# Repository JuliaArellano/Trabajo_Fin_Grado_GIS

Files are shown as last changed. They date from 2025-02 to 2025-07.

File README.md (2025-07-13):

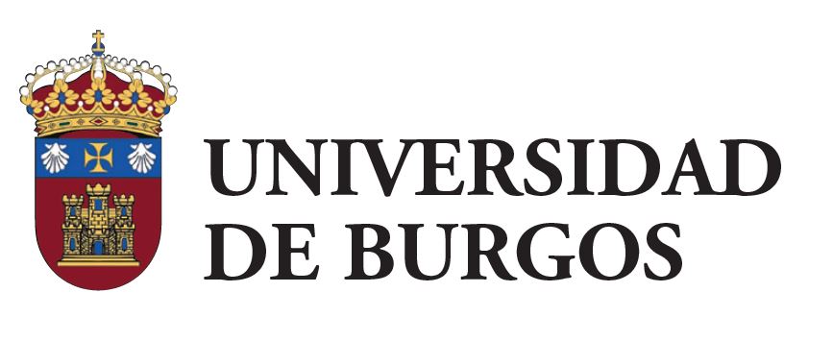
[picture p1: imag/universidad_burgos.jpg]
# Estudio de Viabilidad y Diseño Conceptual de un Stent Arterial Inteligente con regulación basada en sensores. 
**Autora:** Julia Arellano Atienza  
**Tutor:** Guirguis Zaki Guirguis Abdelmessih  
**Grado en Ingeniería de la Salud**  
**Universidad de Burgos** 

---

## Introducción

Las enfermedades cardiovasculares representan aproximadamente el 32 % de todas las muertes a nivel mundial, situándose como la principal causa de fallecimiento. Entre las patologías más comunes se encuentra la arterioesclerosis, caracterizada por el estrechamiento de las arterias debido a la acumulación de placas de ateroma, lo que limita el flujo sanguíneo y puede derivar en eventos isquémicos graves, como infarto de miocardio o accidente cerebrovascular.

Para tratar estas obstrucciones, la implantación de stents es una estrategia habitual que permite mantener abierto el vaso sanguíneo afectado y restaurar el flujo sanguíneo. Desde su introducción, los stents han evolucionado incluyendo variantes farmacoactivas y recubiertas con polímeros para reducir complicaciones. Sin embargo, aún presentan limitaciones importantes: entre un 20 % y un 30 % de los pacientes desarrollan reestenosis (re-estrechamiento del vaso) y existe riesgo de trombosis del stent, complicación potencialmente mortal. Además, los stents actuales carecen de mecanismos de monitorización en tiempo real, dificultando la detección precoz de estas complicaciones.

Frente a esta necesidad, surgen los stents inteligentes con sensores integrados, capaces de monitorizar parámetros fisiológicos como presión, flujo o rigidez arterial, proporcionando datos continuos para la evaluación clínica y la personalización del tratamiento.

---
## Objetivo General

El presente proyecto tiene como objetivo el diseño conceptual de un stent inteligente con sensores integrados, orientado a mejorar la detección precoz de complicaciones como la reestenosis y la trombosis, así como a facilitar un seguimiento más efectivo y personalizado de los pacientes tras la intervención.

El proyecto incluye el diseño y evaluación del prototipo conceptual mediante análisis bibliográfico y modelado matemático, buscando su viabilidad funcional y su posible aplicación clínica futura.

---
## Resultados

A continuación se muestra el diseño 3D del stent inteligente desarrollado:

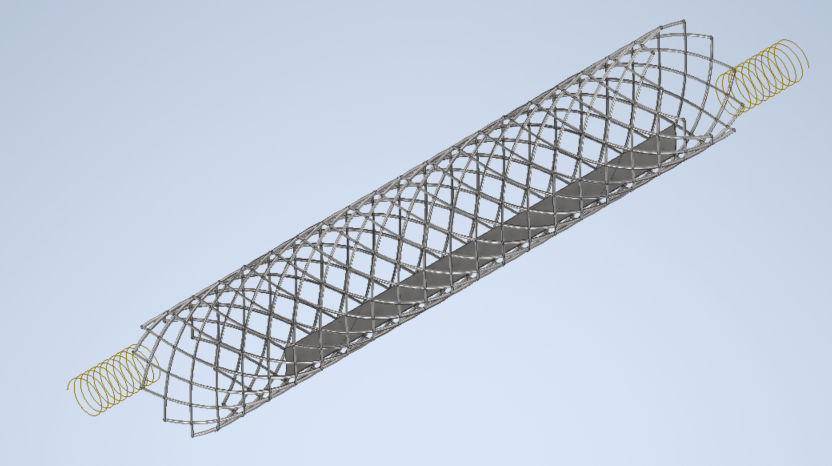
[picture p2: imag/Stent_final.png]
Modelo 3D del Stent Inteligente
  
*Figura 1. Vista del stent inteligente.*

También se ha implementado una aplicación interactiva que permite visualizar el stent, simular su comportamiento ante distintas condiciones y analizar los parámetros del sistema:

🔗 [Haz clic aquí para acceder a la aplicación](https://tfg-gis-stent-inteligente.streamlit.app/)

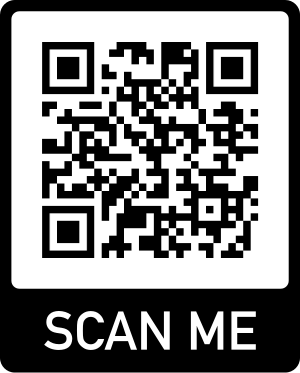
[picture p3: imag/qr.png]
Aplicación
  
*Figura 2. QR de la aplicación.*

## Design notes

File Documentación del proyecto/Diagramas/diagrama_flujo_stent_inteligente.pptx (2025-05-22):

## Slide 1

INICIO

Transmisión energía

LOCALIZACIÓN: PARCHE RECEPTOR

LOCALIZACIÓN: STENT INTELIGENTE

Bobinas reciben la señal electromagnética

Circuito LC se activa y mide la capacitancia (sensor)

Se transmiten los datos a través de las bobinas

¿Se reciben los datos por la bobina del parche?

Procesa y transforma los datos recibidos

Transmite los datos recibidos vía Bluetooth

No

LOCALIZACIÓN: PARCHE RECEPTOR

Sí

Microcontrolador

LOCALIZACIÓN: SISTEMA RECEPTOR

Recibe los datos y los muestra

FIN

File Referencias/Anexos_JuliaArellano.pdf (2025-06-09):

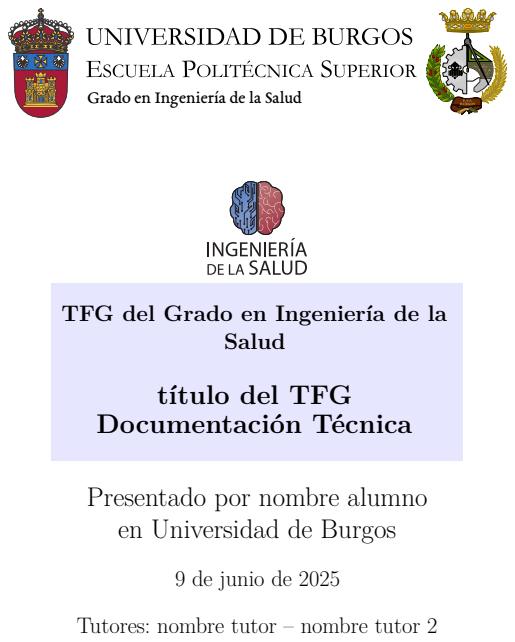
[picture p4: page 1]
Salud

Grado en Ingeniería de la Salud

TFG del Grado en Ingeniería de la

título del TFG
Documentación Técnica

Presentado por nombre alumno
en Universidad de Burgos

9 de junio de 2025

Tutores: nombre tutor – nombre tutor 2

# Índice general

Índice general | i
Índice de figuras | iii
Índice de tablas | v
Apéndice A Plan de Proyecto Software | 1
Apéndice B Documentación de usuario | 9
B.1. Requisitos software y hardware para ejecutar el proyecto. . . | 9

Apéndice C Manual del desarrollador / programador / in-
vestigador. | 11
C.4. Instrucciones para la modificación o mejora del proyecto. . . | 12

Apéndice D Descripción de adquisición y tratamiento de datos 13

Apéndice E Manual de especificación de diseño | 21

i

ii | Índice general
Apéndice F Especificación de Requisitos | 31
Apéndice G Estudio experimental | 33
Apéndice H Anexo de sostenibilización curricular | 63
Bibliografía | 67

# Índice de figuras

A.1. Planificación temporal . Fuente Propia | | 7
D.1. Estructura del Stent. Fuente Propia | | 17
D.2. (a) Posición del sensor en el stent y (b) Estructura del stent.
Fuente propia | | 18
D.3. Estructura de las bobinas. Fuente Propia | | 19
E.1. Plano del diseño inicial del stent . Fuente Propia | | 23
E.2. Plano del diseño stent inteligente . Fuente Propia | | 23
E.3. Plano del diseño del sensor capacitivo . Fuente Propia | | 24
E.4. Sección A del plano del sensor . Fuente Propia | | 24
E.5. Esquema eléctrico de conexión entre el stent y el sistema externo.
Fuente propia | 27
E.6. Diagrama de flujo del sistema de comunicación entre el parche externo, el stent inteligente y el dispositivo receptor. Fuente propia. 28
E.7. Diagrama de componentes de la aplicación | 29
E.8. Diagrama de despliegue de la aplicación web en Streamlit Cloud. 29 E.9. Diagrama de secuencia de interacción entre el usuario y el sistema. 30
G.1. Diseño del stent inteligente final. Fuente Propia | 53
G.2. Inicio de la simulación de la expansión del Nitinol (a) y Fin de
la expansión del Nitinol. Fuente Propia | 53
G.3. Simulación de la expansión térmica del diámetro del stent de
Nitinol Fuente Propia | 54
G.4. Simulación de la expansión térmica de la longitud del stent de
Nitinol. Fuente propia | | 55
G.5. Perfil de velocidad en reposo. Fuente Propia | | 56
G.6. Perfil de velocidad en actividad. Fuente propia | | 56

iii

iv | Índice de figuras
G.7. Impacto de la estenosis en el stent. Fuente Propia | | 57
G.8. Analisis de variación de la frecuencia. Fuente Propia | | 59
G.9. Variación de las tensiones en reposo. Fuente Propia | | 61
G.10.Variación de las tensiones en reposo. Fuente Propia | | 62

# Índice de tablas

A.1. Costes de dispositivos hardware | | 2
A.2. Costes de software utilizados en el proyecto | | 3
A.3. Costes de personal estimados para el desarrollo del proyecto. . . | 3
A.4. Resumen de costes totales del proyecto | | 3
D.1. Parámetros técnicos del stent | | 13
D.2. Características técnicas del sensor capacitivo | | 14
D.3. Estructura en capas del sensor capacitivo | | 14
D.4. Parámetros técnicos del sistema de comunicación | | 15
F.1. CU-1 Nombre del caso de uso | | 32
G.1. Configuración de la expansión del Nitinol | | 46
G.2. Parámetros utilizados para el análisis del flujo sanguíneo en el
interior del stent | 48
G.3. Parámetros geométricos utilizados para el cálculo de la inductan-
cia de la bobina integrada en el stent | 49
G.4. Parámetros utilizados para el cálculo de la capacitancia total del
sensor capacitivo | 49
G.5. Parámetros utilizados en el cálculo de la frecuencia de resonancia
del circuito LC | 50
G.6. Parámetros utilizados en el cálculo de la resistencia de la bobina
y el factor de calidad Q | 50
G.7. Parámetros de la bobina externa utilizada para la transmisión
de energía y señal | | 51
G.8. Parámetros utilizados para calcular la distancia máxima | | 52

v

## Apéndice A

# Plan de Proyecto Software

## A.1. Introducción

Para garantizar el desarrollo adecuado del proyecto, es fundamental realizar una planificación estructurada que contemple tanto los aspectos temporales como los recursos económicos necesarios. Además, resulta imprescindible analizar la viabilidad legal para asegurar que el diseño y aplicación del sistema propuesto cumpla con la normativa vigente. A continuación, se detalla la planificación temporal, económica y legal del proyecto.

## A.2. Planificación temporal

Para el desarrollo del presente trabajo se ha seguido una metodología combinada basada en el modelo en cascada y ciertos principios de Scrum, con el fin de estructurar el proceso de forma clara pero manteniendo flexibilidad ante posibles cambios o mejoras.

El proyecto se ha dividido en hitos principales (milestones), cada uno de los cuales agrupa un conjunto de tareas específicas (issues) que responden a un objetivo común dentro del desarrollo del stent inteligente. Estos hitos incluyen desde la investigación inicial, pasando por el diseño básico y la integración de sensores, hasta el análisis de viabilidad, el desarrollo de la aplicación de visualización y la documentación final.

El enfoque en cascada permite avanzar de manera secuencial a través de las distintas fases del proyecto.No obstante, se han incorporado también prácticas propias de metodologías ágiles como Scrum, especialmente a través de reuniones periódicas de seguimiento semanal, que han facilitado el control

| 1

2 | Apéndice A. Plan de Proyecto Software

de avances, la detección temprana de dificultades y la incorporación de mejoras sobre la marcha.

La planificación del proyecto se representa en el diagrama de Gantt (figura A.1), donde se distingue en azul la planificación inicial y en verde la planificación finalmente llevada a cabo. Esta estructura ha sido clave para cumplir los plazos establecidos y mantener un flujo de trabajo constante y ordenado.

### A.2.1. Planificación económica

A continuación, se presenta la planificación económica del proyecto, en la que se estiman los recursos necesarios y los costes asociados al desarrollo del Trabajo Fin de Grado.

Costes de hardware

En el desarrollo de este proyecto únicamente se ha utilizado un dispositivo físico (un ordenador portátil). Para estimar su coste dentro del marco del Trabajo Fin de Grado, se ha calculado la amortización considerando una vida útil media del dispositivo de 4 años y en función de los 6 meses de duración del proyecto. En la Tabla A.1 se recoge el desglose de este coste

Dispositivo | Coste total | Amortización (6 meses)
Ordenador portátil V15 G2 ITL | 695,13 € [1] | 86,98 €

Tabla A.1: Costes de dispositivos hardware.

Costes de sotfware

En cuanto al software, se ha utilizado la versión gratuita de Anaconda (Python) y Streamlit, ambas de libre acceso, junto con Autodesk Inventor, para el diseño del stent, que dispone de una licencia de pago cuyo coste mensual se ha tenido en cuenta para calcular el coste total proporcional al uso durante los 6 meses del proyecto.

La Tabla A.2 resume los costes asociados a cada una de las herramientas.

Costes de personal

Para calcular los costes de personal correspondientes al desarrollo de este diseño de prototipo, se ha tomado como referencia el salario medio de un ingeniero biomédico contratado bajo un contrato indefinido en régimen

A.2. Planificación temporal | 3
Software | Tipo de licencia | Amortización (6 meses)
Autodesk Inventor | Licencia de pago (472 €/mes)[2] | 2.832 €
Anaconda (Python) | Gratuita | 0 €
Streamlit | Gratuita | 0 €

Tabla A.2: Costes de software utilizados en el proyecto.

general y a tiempo parcial de 5 horas diarias, considerando una duración del proyecto de 6 meses.

La Tabla A.3 detalla el desglose de los costes.

Concepto | Coste
Salario bruto mensual (5 horas diarias) | 1.743,75 € [3]
Coste seguridad social empresa (32,07 %) | 652,43 €[4]
Coste total mensual | 2.396,18 €
Coste total para 6 meses | 14.377,06 €

Tabla A.3: Costes de personal estimados para el desarrollo del proyecto.

Coste total

El precio de los materiales no se ha tenido en cuenta en este trabajo, ya que el diseño del prototipo se ha realizado únicamente de forma digital, dibujado con software especializado, sin llevar a cabo la fabricación o creación del dispositivo físico. Por tanto, los costes reflejados en la tabla A.4, corresponden exclusivamente al desarrollo del diseño digital y al uso del software necesario.

Concepto | Coste
Coste hardware Coste software Coste de personal | 86,98 € 2.832,00 € 14.377,08 €
Coste total estimado | 17.296,06

Tabla A.4: Resumen de costes totales del proyecto.

4 | Apéndice A. Plan de Proyecto Software
A.3. | Viabilidad legal

El desarrollo de un stent inteligente implantable requiere cumplir con una serie de normativas y regulaciones legales que garanticen su seguridad, eficacia, trazabilidad, protección industrial y tratamiento ético de los datos. Esta sección aborda la viabilidad legal considerando una futura fabricación, ensayo clínico y comercialización del dispositivo.

### A.3.1. Regulación Europea de Productos Sanitarios

El dispositivo se clasifica como un producto sanitario activo implantable de clase III, en base al Reglamento (UE) 2017/745 sobre productos sanitarios[5] que entra en vigor 25/05/2017 y en España se aplica desde 26/05/2021, denominado Medical Device Regulation (MDR). Esta normativa establece requisitos estrictos para productos de alto riesgo, incluyendo:

Evaluación clínica y elaboración del expediente técnico.

Aplicación de un sistema de gestión de calidad (ISO 13485)[6].

Gestión de riesgos según la norma ISO 14971[6].

Estudios de biocompatibilidad (ISO 10993)[6].

Obtención del marcado CE.

### A.3.2. Intervención de la AEMPS

La Agencia Española de Medicamentos y Productos Sanitarios (AEMPS) es el organismo competente en España para la supervisión, evaluación y autorización de productos sanitarios implantables [7]. Antes de su uso en humanos, el dispositivo requeriría:

Autorización para ensayos clínicos por parte de la AEMPS.

Aprobación por un Comité Ético de Investigación con medicamentos (CEIm).

Conformidad con los procedimientos definidos en el MDR y las guías técnicas nacionales.

A.3. Viabilidad legal | 5
A.3.3. | Normas Técnicas Aplicables

Durante el desarrollo del prototipo deben considerarse normas técnicas armonizadas con la legislación vigente, entre ellas:

ISO 13485: Gestión de calidad en productos sanitarios[6].

ISO 14971: Gestión del riesgo[6].

ISO 10993: Evaluación biológica de materiales[6].

ISO 25539: Requisitos específicos para stents vasculares[6].

ISO 14708-1: Dispositivos implantables activos electrónicos[6].

### A.3.4. Protección de la Propiedad Industrial

El diseño del stent inteligente podría ser registrado como patente conforme a la 24/2015, de Patentes [8]. Para ello, la invención debe cumplir los siguientes criterios:

Novedad.

Actividad inventiva.

Aplicación industrial.

La solicitud se tramitaría ante la Oficina Española de Patentes y Marcas (OEPM) y, posteriormente, podría extenderse internacionalmente mediante el Tratado de Cooperación en materia de Patentes (PCT) o a través de la Oficina Europea de Patentes (EPO).

### A.3.5. Protección de Datos Personales

En el caso de que el dispositivo se comercialice o se utilice en ensayos clínicos reales, será obligatorio cumplir con la normativa sobre protección de datos:

Reglamento General de Protección de Datos (RGPD) (UE) 2016/679 [9].

Ley Orgánica 3/2018, de Protección de Datos Personales y Garantía de los Derechos Digitales (LOPDGDD) [10].

6 | Apéndice A. Plan de Proyecto Software

Estas normativas regulan el tratamiento de datos personales de pacientes, estableciendo que:

El paciente debe otorgar un consentimiento informado específico y explícito.

Los datos deben ser anonimizados o pseudonimizados en los estudios.

Es necesaria la implementación de medidas técnicas y organizativas para garantizar la seguridad de la información.

### A.3.6. Equipos de Comunicación Inalámbrica

El sistema de comunicación inductiva incorporado al stent debe cumplir con la directiva 2014/53/UE (RED) relativa a equipos radioeléctricos [11]. Esta legislación exige:

Cumplimiento con normas de compatibilidad electromagnética (EMC).

Evaluación del uso eficiente del espectro radioeléctrico.

Garantía de que no se generan interferencias con otros dispositivos médicos.

### A.3.7. Conclusión Legal

A pesar de encontrarse en fase de diseño, el stent inteligente propuesto ha sido diseñado considerando los marcos normativos y legales relevantes. En una futura fase de comercialización, el cumplimiento de las directivas europeas, las normas ISO aplicables, la regulación española (AEMPS y OEPM) y la legislación de protección de datos asegurará la viabilidad legal del proyecto.

A.3. Viabilidad legal | 7

Figura A.1: Planificación temporal . Fuente Propia

## Apéndice B

# Documentación de usuario

B.1. Requisitos software y hardware para ejecutar el proyecto.

ver os requistos y decidir

B.2. | Instalación / Puesta en marcha
B.3. | Manuales y/o Demostraciones prácticas

9

## Apéndice C

# Manual del desarrollador /

programador / investigador.

## C.1. Estructura de directorios

Descripción de los directorios y ficheros entregados.

## C.2. Compilación, instalación y ejecución del proyecto

En caso de ser necesaria esta sección, porque la compilación o ejecución no sea directa.

## C.3. Pruebas del sistema

Esta sección puede ser opcional.

Puede tratarse de validación de la interfaz por parte de los usuarios, mediante escuestas o similar o validación del funcionamiento mediante pruebas unitarias.

| 11

12 | Apéndice C. Manual del desarrollador / programador / investigador.
C.4. | Instrucciones para la modificación o
mejora del proyecto.

Instrucciones y consejos para que el trabajo pueda ser mejorado en futuras ediciones.

## Apéndice D

# Descripción de adquisición y tratamiento de datos

## D.1. Descripción formal de los datos

Los datos correspondientes a este trabajo son los parámetros técnicos utilizados para el diseño conceptual del stent inteligente.

### D.1.1. Stent

Los valores definidos para la estructura del stent se muestran en la Tabla D.1.

Parámetro | Valor
Diámetro expandido Longitud total Espesor del hilo Tamaño del paso Número de hilos Material del stent | 3.55 mm 20 mm 0.1 mm 10 mm 6 hilos Nitinol

Tabla D.1: Parámetros técnicos del stent

13

14 | Apéndice D. Descripción de adquisición y tratamiento de datos
D.1.2. | Sensor capacitivo

Los valores relacionados con el sensor se muestran en la Tabla D.2.

Parámetro | Valor
Ubicación Dimensiones Espesor total del sensor Número de electrodos Dimensiones de los electro-dos Separación entre electrodos | Superficie interna del stent 1,05 mm × 15 mm 16 µm 48 pares 350 µm x 150µm 5 µm

Tabla D.2: Características técnicas del sensor capacitivo

Capas del sensor

Las capas que componen el sensor capacitivo se detallan en la Tabla D.3.

Capa | Material | Espesor
Capa superior Electrodo superior Capa intermedia Electrodo inferior Capa inferior Recubrimiento externo | Poliimida (PI) Nanopartículas de plata (AgNP) Poliimida (PI) (2 Capas super-puestas de 2.5 µm) Nanopartículas de plata (AgNP) Poliimida (PI) PDMS | 2.5 µm 1 µm 5 µm 1 µm 2.5 µm 4 µm

Tabla D.3: Estructura en capas del sensor capacitivo

D.1. Descripción formal de los datos | 15
D.1.3. | Sistema de comunicación

La información técnica del sistema de comunicación se basa en el uso de tecnología de acoplamiento inductivo (circuito LC), donde el condensador
(C) está constituido por el propio sensor capacitivo, mientras que las bobinas
(L) presentan las dimensiones recogidas en la Tabla D.4.
Parámetro | Valor
Ubicación Material conductor Diámetro exterior de la bo-bina Número de vueltas Espesor del hilo Longitud de la bobina | Extremos del stent Oro 1.2 mm 10 10 µm 2,5 cm

Tabla D.4: Parámetros técnicos del sistema de comunicación

### D.1.4. Conexiones

Las pistas conductoras se imprimen directamente sobre la superficie del stent utilizando oro recubiertas con una capa de poliamida. Estas pistas conectan eléctricamente las bobinas con los electrodos interdigitados del sensor. El espesor total de las conexiones es de 1 µm.

### D.1.5. Parche externo

El parche externo es fundamental en el sistema de comunicación inalámbrica y alimentación del stent inteligente. Su función principal sería transferir energía al stent y recibir la información generada por el sensor mediante acoplamiento inductivo, sin necesidad de cables ni contacto directo.

El diseño del parche incluiría los siguientes elementos clave:

Generador de señal u oscilador: Produce una corriente alterna a una frecuencia específica, que alimenta el circuito inductivo LC.

16 | Apéndice D. Descripción de adquisición y tratamiento de datos

Bobina transmisora (Lext): Genera un campo magnético alterno que induce corriente en la bobina del stent, proporcionando la energía necesaria para su funcionamiento.

Capacitor de sintonización (Cext): Forma un circuito resonante LC con la bobina transmisora, optimizando la transferencia de energía y señal entre el parche y el stent.

La bobina transmisora junto con el capacitor constituyen la parte pasiva del sistema, funcionando como circuito resonante o “antena” que permite tanto la transferencia de energía al stent como la recepción de la señal modulada que este transmite.

El circuito receptor activo del parche está compuesto por varios bloques electrónicos que procesan la señal recibida:

Rectificador: Convierte la señal alterna recibida en una señal continua adecuada para su procesamiento.

Conversor analógico-digital (ADC): Digitaliza la señal analógica modulada que proviene del stent.

Microcontrolador (MCU): Procesa y decodifica los datos digitalizados transmitidos desde el sensor capacitivo integrado en el stent.

Módulo Bluetooth Low Energy (BLE): Transmite inalámbricamente los datos procesados a dispositivos externos, como smartphones o sistemas de monitorización remota.

D.2. Descripción clínica de los datos.

Los parámetros definidos para el diseño del stent inteligente tienen como objetivo de tratar enfermedades cardiovasculares, más concretamente lesiones arteriales en arterias coronarias. A continuación, se presenta el significado clínico de cada uno de los parámetros seleccionados.

### D.2.1. Estructura del stent

Se ha seleccionado un diámetro expandido de 3.55 mm para el stent, ya que representa un valor promedio dentro del rango fisiológico de las arterias coronarias humanas, el cual varía entre 3 mm y 6 mm [12]. Esta

D.2. Descripción clínica de los datos. | 17

elección permite garantizar una adecuada apertura de la luz arterial tras la implantación, favoreciendo el restablecimiento del flujo sanguíneo.

La longitud del stent, de 20 mm, ha sido definida para cubrir eficazmente la zona afectada por la estenosis, sin invadir segmentos arteriales sanos. Esta dimensión se encuentra dentro del intervalo clínicamente recomendado para lesiones localizadas, que va de 0 a 20 mm.[12]

El stent está fabricado en Nitinol, una aleación con memoria de forma que permite recuperar su configuración original tras el despliegue en el vaso. Este material se emplea ampliamente en dispositivos médicos por su excelente biocompatibilidad, elasticidad y capacidad de adaptarse a los movimientos de la pared arterial [13].

En cuanto a sus características estructurales, el diseño incluye 6 hilos entrelazados con un espesor de 0.1 mm, que aseguran la estabilidad del dispositivo frente a las presiones internas del vaso sin comprometer su integridad estructural.

En la siguiente imagen, Figura D.1 se puede observar la estructura del stent diseñado

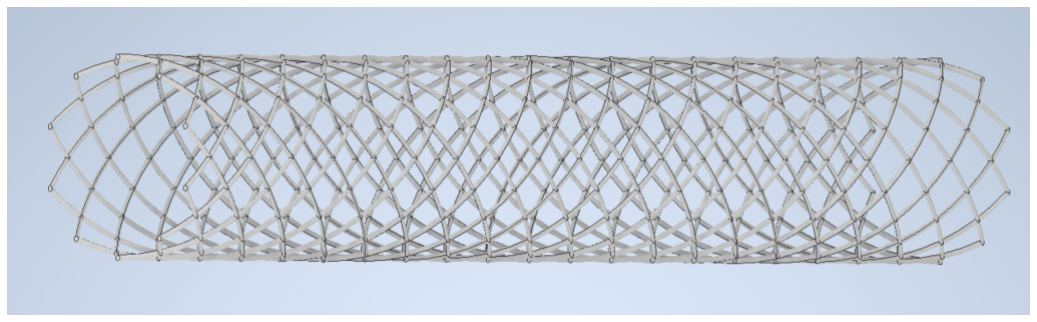
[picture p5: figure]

Figura D.1: Estructura del Stent. Fuente Propia

### D.2.2. Sensor capacitivo

El sensor capacitivo ha sido integrado en la superficie interna del stent, lo que permite obtener información fisiológica del entorno que lo rodea. Sus dimensiones (1.05 mm × 15 mm × 16 µm) han sido definidas para permitir su adaptación longitudinal a la pared interna del stent, sin alterar el flujo sanguíneo.

El número de pares de electrodos y su distribución estratégica permiten captar variaciones de presión o rigidez en la pared arterial. Estos cambios

18 | Apéndice D. Descripción de adquisición y tratamiento de datos

pueden estar relacionados con eventos clínicamente adversos, como reestenosis, trombosis o procesos inflamatorios. Además, la separación entre capas de 5 µm mejora la sensibilidad del sensor ante pequeñas variaciones fisiológicas.

| El sensor está compuesto por capas de materiales biocompatibles, inclu-
yendo poliimida (como capa dieléctrica¹
| ), plata (electrodos) y PDMS. Estos
materiales han sido seleccionados no solo por su buena biocompatibilidad, minimizando el riesgo de rechazo, sino también por su estabilidad eléctrica en el entorno del flujo sanguíneo. La inclusión de PDMS como recubrimiento externo añade flexibilidad y mejora la protección frente al entorno biológico.
| En la Figura D.2 se puede observar el sensor. Cabe destacar que las
capas del sensor no se diferencian bien en la imagen D.2b, ya que están superpuestas. Por lo tanto, para más detalle, véase el plano del sensor ubicado en el Anexo E.

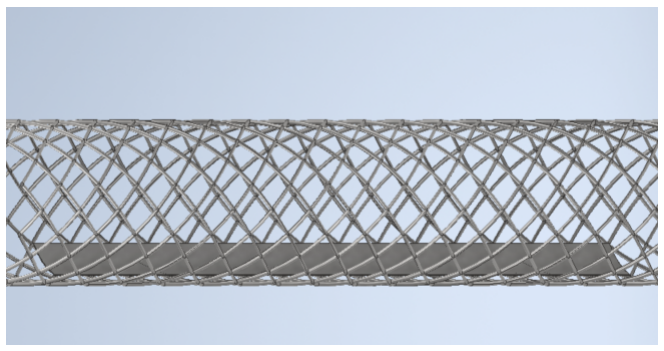
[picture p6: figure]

(a)

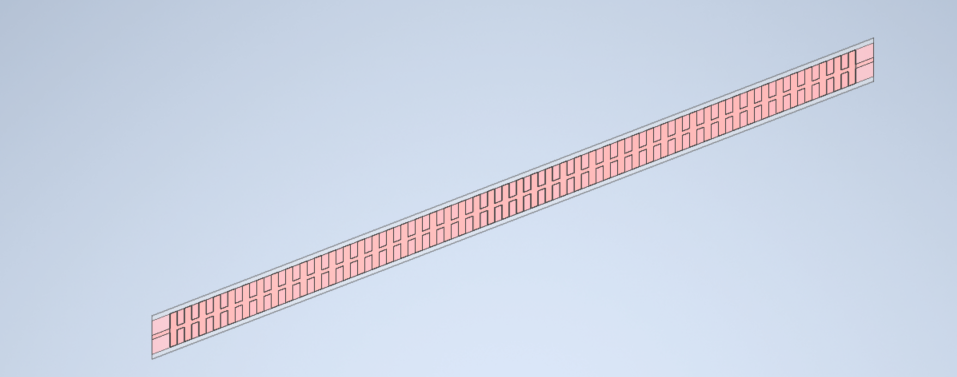
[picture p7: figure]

(b)

Figura D.2: (a) Posición del sensor en el stent y (b) Estructura del stent. Fuente propia.

1
capa dieléctrica: es aquella capa que actúa como un asilante eléctrico que puede polarizarse mediante la aplicación de un campo eléctrico.[14]

D.2. Descripción clínica de los datos. | 19
D.2.3. | Sistema de comunicación

La implementación de un sistema de comunicación por acoplamiento inductivo permite la monitorización remota del sensor sin necesidad de baterías ni conexiones invasivas. Desde el punto de vista clínico, esta estrategia facilita el seguimiento continuo del paciente tras la implantación del stent, posibilitando la detección temprana de complicaciones sin requerir procedimientos diagnósticos invasivos.

Las bobinas inductivas, ubicadas en los extremos del stent, presentan dimensiones de 2.5 cm de longitud, un espesor de hilo de 10 µm y un diámetro de giro de 1.2 mm. Estas han sido diseñadas para generar un campo electromagnético que, al entrar en resonancia con el sensor capacitivo, permite la transmisión inalámbrica de datos hacia el exterior.

Estas bobinas han sido fabricadas con oro, un material elegido por su excelente conductividad eléctrica, alta resistencia a la corrosión y biocompatibilidad, características fundamentales para dispositivos implantables. El uso de oro también contribuye a mantener una señal estable y eficiente en un entorno fisiológico complejo como el torrente sanguíneo, donde otros materiales podrían degradarse o generar reacciones adversas.

Este enfoque es totalmente compatible con las tecnologías médicas actuales y forma parte de la evolución hacia dispositivos implantables inteligentes, capaces de proporcionar información en tiempo real sobre el estado fisiológico del paciente.

En la siguiente imagen, Figura D.3, se muestra una de las bobinas, ya que ambas presentan un diseño idéntico.

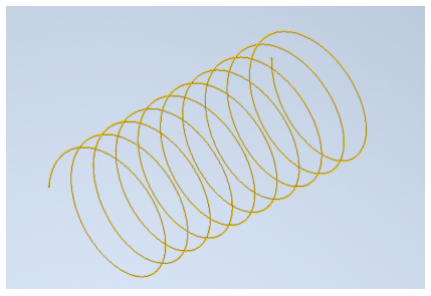
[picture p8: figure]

Figura D.3: Estructura de las bobinas. Fuente Propia

20 | Apéndice D. Descripción de adquisición y tratamiento de datos
D.2.4. | Conexiones

Desde el punto de vista clínico, las conexiones permiten transmitir la señal del sensor al sistema de comunicación de forma segura y eficaz dentro del entorno corporal. Se utilizan pistas conductoras de oro, un material seleccionado por su alta biocompatibilidad y resistencia a la corrosión en medios biológicos. Estas pistas están recubiertas con una capa de poliimida, que actúa como aislante para evitar el contacto directo con los tejidos y minimizar el riesgo de reacciones adversas. Todo ello asegura la estabilidad eléctrica del sistema y su integración segura en el entorno vascular.

### D.2.5. Parche externo

Desde el punto de vista clínico, el parche externo actúa como interfaz entre el paciente y el entorno médico. Su capacidad para alimentar el stent inteligente y recibir datos en tiempo real permite transformar el stent inteligente en un sistema activo de monitorización continua, sin necesidad de procedimientos invasivos o complejos.

Este tipo de tecnología resulta especialmente útil en el seguimiento en tiempo real de pacientes con enfermedad arterial coronaria, permitiendo la recogida de datos hemodinámicos directamente desde el interior de la arteria. El uso del parche, colocado de forma superficial sobre la piel proporciona una solución cómoda y no invasiva, lo que facilita su uso regular por parte del paciente fuera del entorno hospitalario.

Mediante el módulo de comunicación Bluetooth Low Energy (BLE), los datos adquiridos pueden ser enviados automáticamente a plataformas médicas o aplicaciones móviles, lo que favorece la integración del sistema en entornos de telemedicina personalizada y de monitorización domiciliaria en tiempo real. Esta capacidad resulta especialmente valiosa para detectar de forma precoz eventos adversos como la reestenosis, trombosis o signos de fallo del stent.

## Apéndice E

# Manual de especificación de diseño

En este apéndice se presenta una visión general de los diseños desarrollados en el proyecto, abarcando tanto el dispositivo físico (stent) como la aplicación informática que facilita la visualización de los ensayos de viabilidad.

El contenido se organiza en dos secciones principales: la primera aborda el diseño estructural del stent mediante planos y esquemas que permiten entender su funcionamiento; la segunda describe el diseño de la aplicación desarrollada, incluyendo su arquitectura de software, diagramas de clases y despliegue.

## E.1. Diseño físico

En esta sección se presentan los planos del stent inteligente y del sensor integrado, mostrando únicamente la geometría general del dispositivo. Las acotaciones siguen la normativa ISO y están indicadas en milímetros, con el objetivo de facilitar la comprensión visual del diseño desarrollado.

### E.1.1. Planos

Cabe destacar que, inicialmente, se realizó un diseño preliminar que representa la estructura base del stent. A continuación, se muestra el plano correspondiente en la Figura E.1.

21

22 | Apéndice E. Manual de especificación de diseño
| Tras ello, se presenta el plano correspondiente al diseño final del stent
inteligente, Figura E.2, en el cual se pueden visualizar todos los componentes integrados, junto con sus respectivas acotaciones.
| Seguidamente, se presenta el plano del sensor capacitivo (Figura E.3).
Este se basa en una estructura tipo sándwich, compuesta (de la capa superior a la inferior) PI_up_2 – AgNP_up – PI_up_1 – PI_bottom_1 – AgNP_bottom – PI_bottom_2, con un recubrimiento externo de PDMS. Para facilitar la diferenciación visual en el plano, las capas de poliamida se han representado en color rojo.
| En la Sección A del plano se ha realizado un aumento de 300:1 con el
fin de visualizar correctamente las acotaciones correspondientes al espesor de cada capa, ya que estas presentan dimensiones muy reducidas. Esta ampliación puede observarse en la Figura E.4.
| Por último, se incluye un esquema representativo del sistema de comu-
nicación entre el stent inteligente y el circuito externo (Figura E.5). En él se detallan tanto las conexiones internas del stent inteligente como las del parche exterior. Este esquema tiene como objetivo conocer las conexiones necesarias para el funcionamiento general del sistema creado.

### E.1.2. Diagramas

A continuación, se presenta un diagrama de flujo, Figura E.6, que resume el proceso de comunicación entre el sistema externo (parche) y el stent inteligente, así como la posterior transmisión de datos hacia el dispositivo receptor. Este esquema permite comprender de manera visual la secuencia de funcionamiento del sistema en condiciones normales.

## E.2. App de visualización

La aplicación informática desarrollada en este proyecto no está destinada a la recepción de datos biomédicos en tiempo real desde el stent inteligente, sino que tiene como objetivo principal facilitar la visualización e interpretación de los ensayos de viabilidad realizados. Esta fue desarrollada desarrollada con el framework Streamlit en Python, lo que permite ofrecer una interfaz web sencilla e interactiva para el usuario.

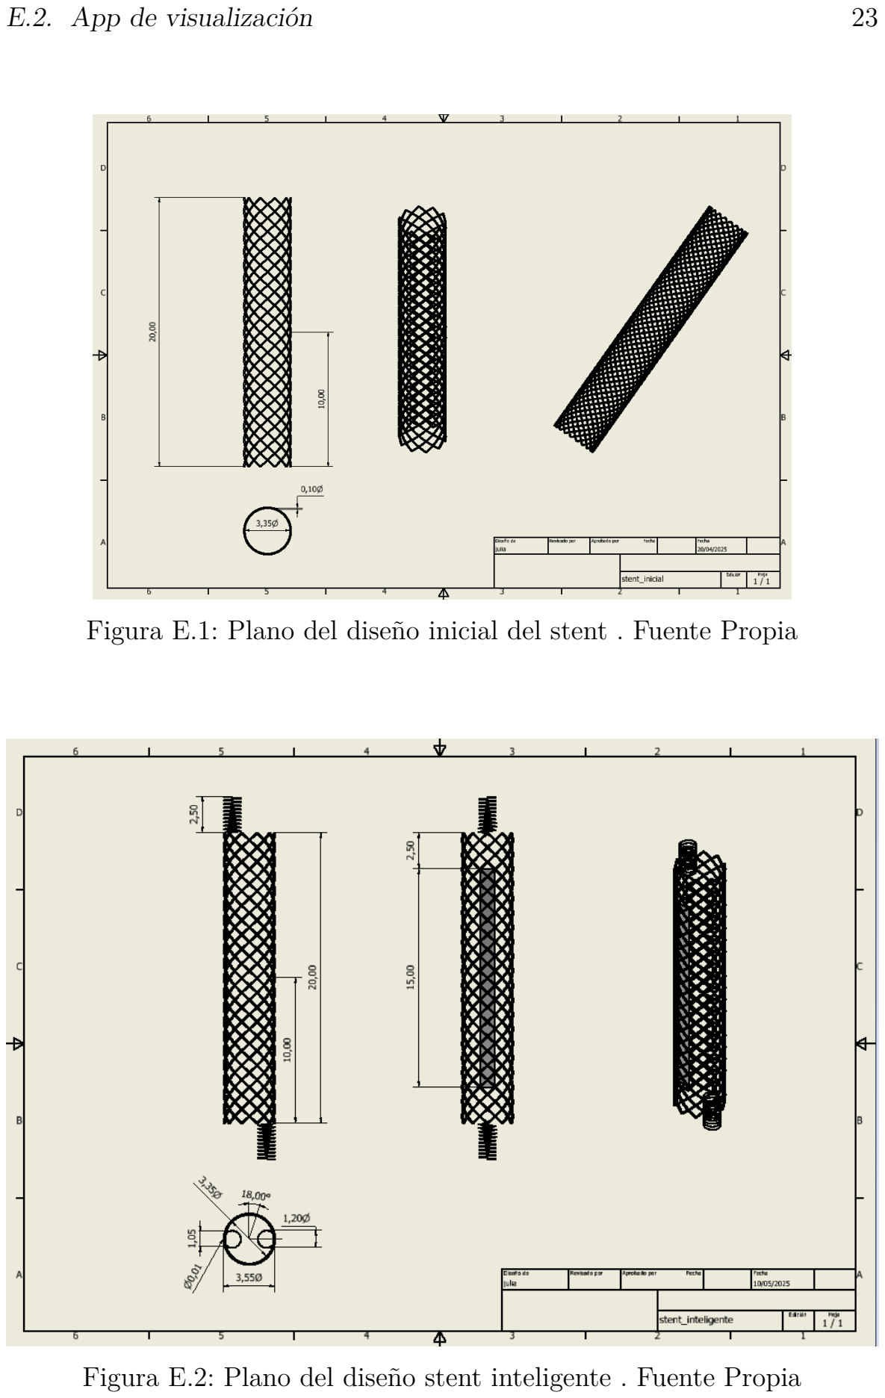
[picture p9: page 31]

E.2. App de visualización | 23

Figura E.1: Plano del diseño inicial del stent . Fuente Propia

Figura E.2: Plano del diseño stent inteligente . Fuente Propia

24 | Apéndice E. Manual de especificación de diseño

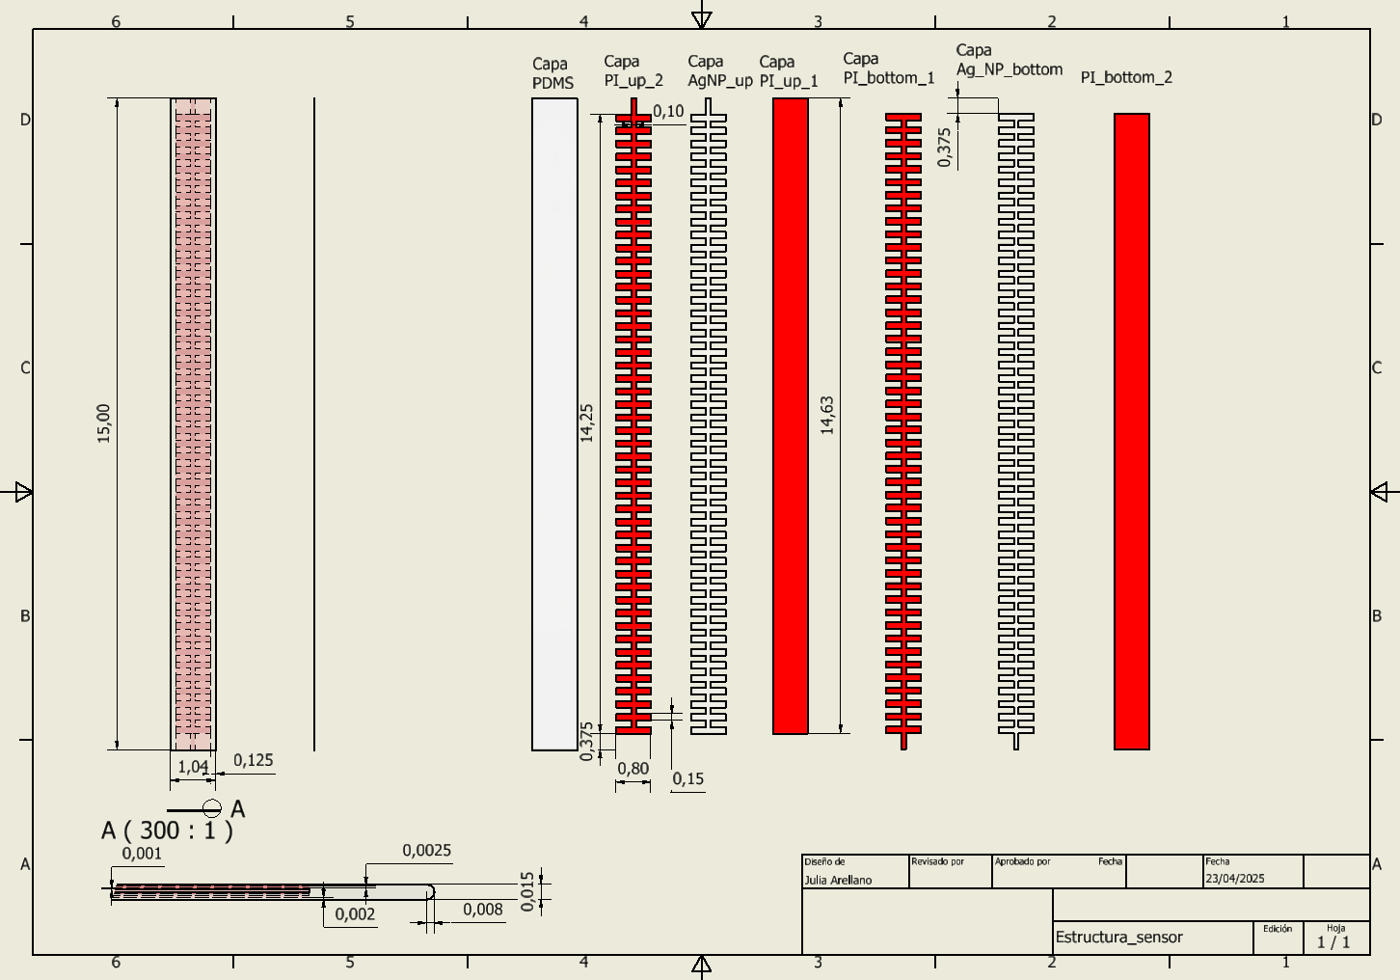
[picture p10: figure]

Figura E.3: Plano del diseño del sensor capacitivo . Fuente Propia

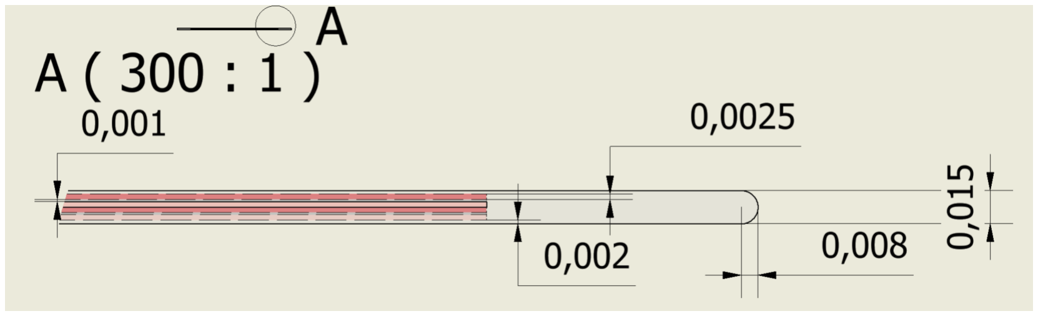
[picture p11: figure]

Figura E.4: Sección A del plano del sensor . Fuente Propia

E.2. App de visualización | 25
E.2.1. | Diseño arquitectónico

La aplicación ha sido desarrollada con una estructura modular, lo que permite una navegación intuitiva y una clara separación entre los distintos ensayos realizados para evaluar el funcionamiento del stent inteligente. En la Figura E.7 se presenta el diagrama de componentes, el cual refleja la estructura lógica de la aplicación. Cada módulo, con excepción del inicio, está asociado a uno de los ensayos descritos en el Anexo G, los cuales simulan el comportamiento del sistema en diversas condiciones. Los módulos realizados fueron:

Inicio: Pantalla inicial con información general.

Vista 3D: Visualización tridimensional del stent mediante archivos STL.

Flujo sanguíneo: Representación del comportamiento del flujo tras la implantación.

Expansión térmica: Simulación del efecto de la temperatura en el Nitinol.

Parámetros del circuito LC: Cálculo de capacitancia, inductancia y frecuencia de resonancia.

Análisis del sistema de comunicación: Estimación del factor de calidad y distancia de transmisión.

Análisis mecánico: Evaluación de tensiones estructurales en el stent.

Despliegue de la aplicación

La Figura E.8 muestra el diagrama de despliegue, el cual representa cómo se despliega la aplicación en un entorno cliente-servidor, utilizando la plataforma Streamlit Cloud.

El código de la aplicación, escrito en Python, se ejecuta en el servidor y se comunica con el navegador del usuario mediante el protocolo HTTP/HTTPS. El usuario puede modificar parámetros, cargar archivos y visualizar los resultados dinámicamente desde su navegador web, sin necesidad de instalaciones locales.

26 | Apéndice E. Manual de especificación de diseño

Interacción usuario-aplicación

| La Figura E.9 presenta el diagrama de secuencia, el cual describe el flujo
de interacción entre el usuario y los distintos componentes del sistema.
| Cuando el usuario modifica un valor o carga un archivo, estos datos
se envían al servidor Streamlit, el cual los procesa y ejecuta los cálculos correspondientes mediante el backend en Python. Una vez obtenidos los resultados, la interfaz se actualiza automáticamente con gráficos y resultados interactivos.

E.2. App de visualización | 27

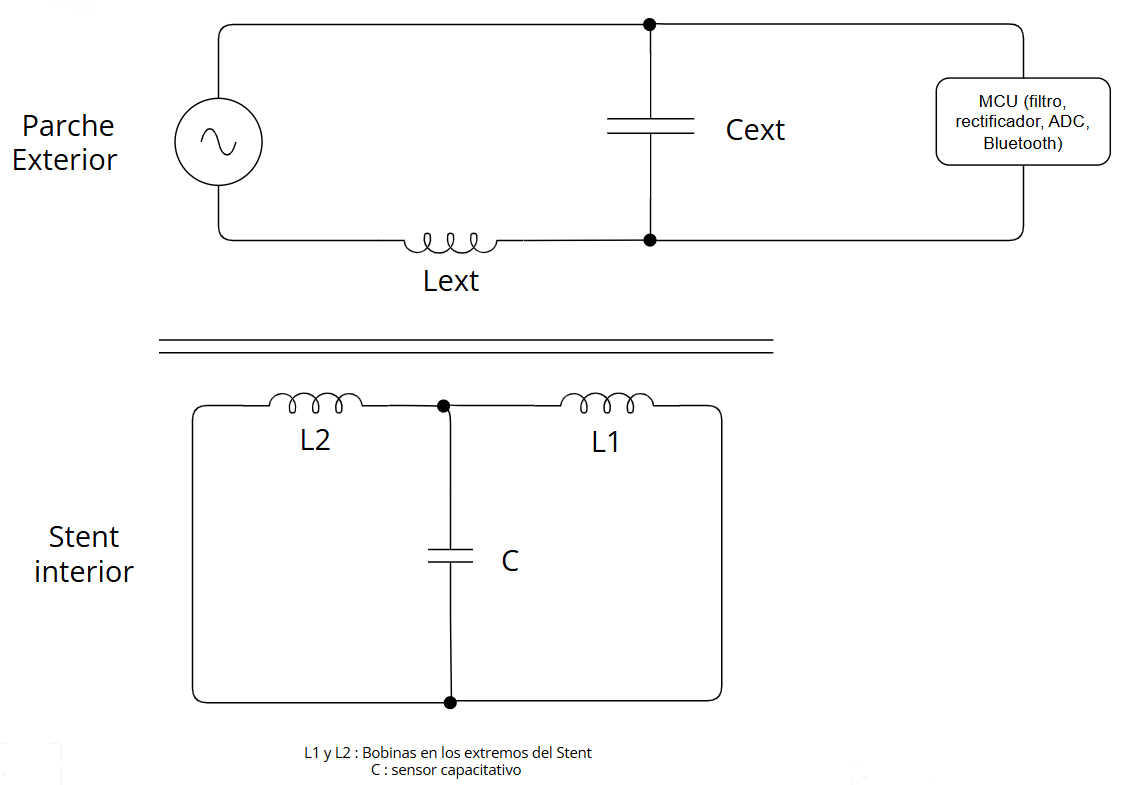
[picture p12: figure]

Figura E.5: Esquema eléctrico de conexión entre el stent y el sistema externo. Fuente propia.

28 | Apéndice E. Manual de especificación de diseño

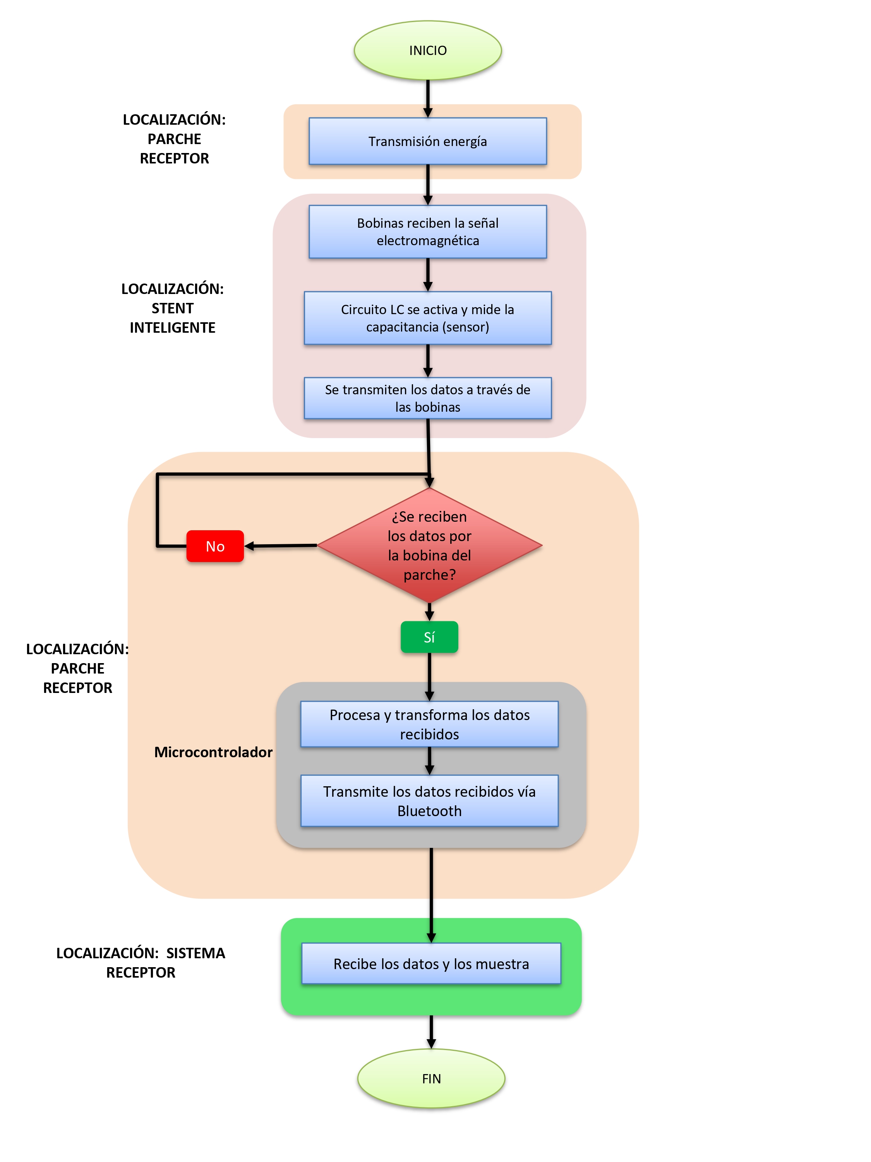
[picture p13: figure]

Figura E.6: Diagrama de flujo del sistema de comunicación entre el parche externo, el stent inteligente y el dispositivo receptor. Fuente propia.

E.2. App de visualización | 29

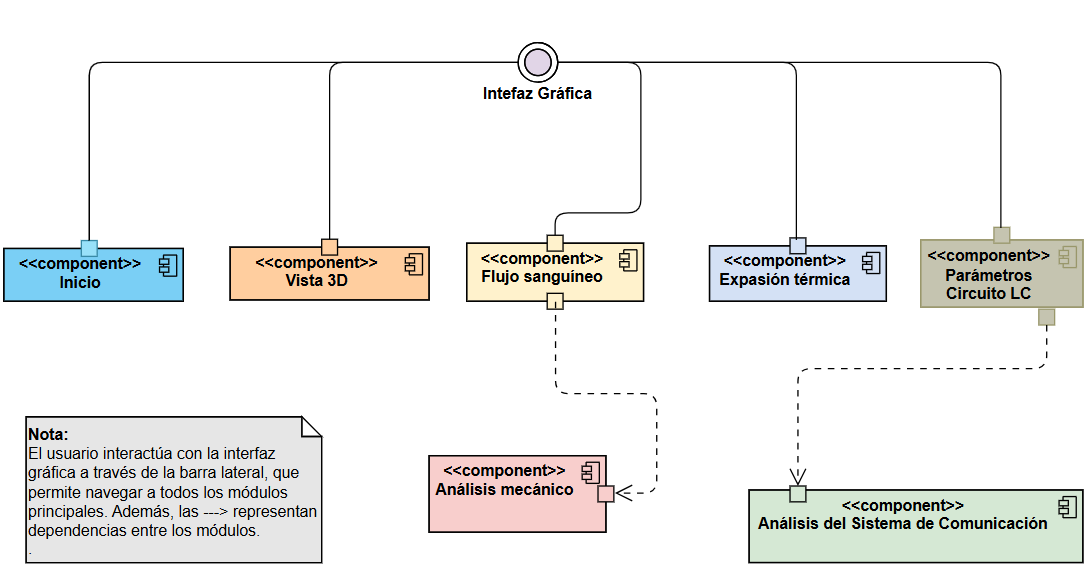
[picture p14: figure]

Figura E.7: Diagrama de componentes de la aplicación.

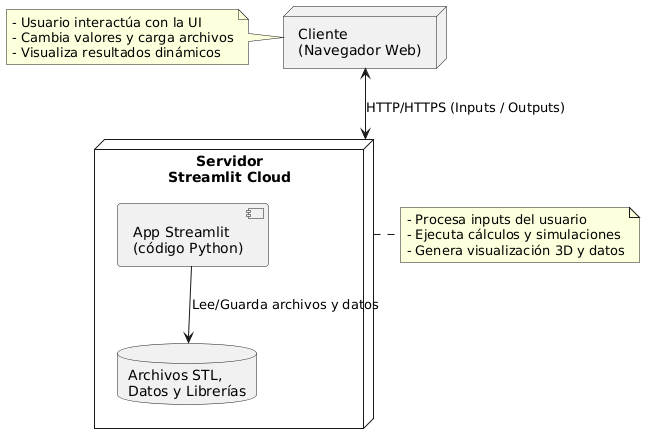
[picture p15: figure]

Figura E.8: Diagrama de despliegue de la aplicación web en Streamlit Cloud.

30 | Apéndice E. Manual de especificación de diseño

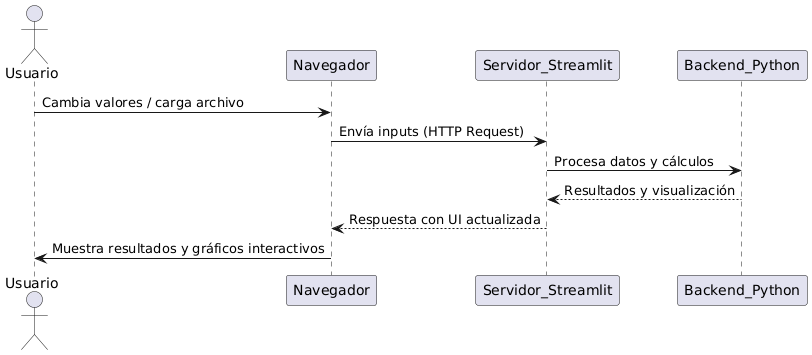
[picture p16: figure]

Figura E.9: Diagrama de secuencia de interacción entre el usuario y el sistema.

## Apéndice F

# Especificación de Requisitos

Si procede.

F.1. | Diagrama de casos de uso
F.2. | Explicación casos de uso.

Se puede describir mediante el uso de tablas o mediante lenguaje natural.

Una muestra de cómo podría ser una tabla de casos de uso:

F.3. Prototipos de interfaz o interacción con el proyecto.

31

32 | Apéndice F. Especificación de Requisitos
CU-1 | Ejemplo de caso de uso
Versión | 1.0
Autor | Alumno
Requisitos asociados | RF-xx, RF-xx
Descripción | La descripción del CU
Precondición | Precondiciones (podría haber más de una)
Acciones
1. Pasos del CU
2. Pasos del CU (añadir tantos como sean necesa-
| rios)

Postcondición Postcondiciones (podría haber más de una)
Excepciones | Excepciones
Importancia | Alta o Media o Baja...
| Tabla F.1: CU-1 Nombre del caso de uso.

## Apéndice G

# Estudio experimental

G.1. | Cuaderno de trabajo
G.1.1. | Elaboración del stent inteligente

Inicialmente, se llevó a cabo una fase de familiarización con el software Autodesk Inventor. Durante esta etapa, se exploraron algunas de sus funcionalidades básicas, ya que nunca se había utilizado previamente un software de diseño. Esto conllevó varios intentos para generar una simple tubería y, posteriormente, los primeros bocetos de un stent genérico, aún sin características definidas. Esta fase fue clave para adquirir soltura en el entorno de modelado 3D y comprender mejor las limitaciones geométricas y estructurales del dispositivo.

Posteriormente, se realizó una revisión bibliográfica centrada en artículos científicos sobre stents inteligentes. Esta investigación permitió recopilar parámetros técnicos fundamentales (como dimensiones, materiales, estructuras internas, tecnologías de comunicación, entre otros), y sirvió como base para el planteamiento del diseño final del dispositivo.

Una vez definidos los requisitos del diseño, se procedió a modelar el stent inteligente. Este se basó en una malla helicoidal que permite integrar un sensor capacitivo flexible en la superficie interna del dispositivo, así como bobinas en sus extremos. El proceso de diseño comenzó con la creación de un primer boceto en el que se dibujó un círculo que representa el radio interior del stent, junto con otro círculo correspondiente a la sección del hilo del stent, también incluyo la sección transversal del sensor capacitivo. Como la estructura requiere seis hilos, se utilizó una operación de patrón

| 33

34 | Apéndice G. Estudio experimental

para repetir este segundo círculo seis veces, ubicándolos equidistantemente en las posiciones adecuadas.A continuación, se creó un segundo boceto, en un plano perpendicular al primero, en el que se dibujó una línea que sirvió como trayectoria para generar la forma helicoidal del stent mediante una operación de extrusión (Bobina). Esta extrusión helicoidal se realizó en ambas direcciones para conformar la estructura completa del stent. Posteriormente, se extruyó el sensor capacitivo ubicado en la superficie del stent, utilizando la sección definida previamente en el primer boceto, junto con una restricción de desplazamiento que permitió posicionarlo correctamente sobre la estructura. En el diseño final, este sensor se modeló como un sólido integrado en el cuerpo del stent. Finalmente, se incorporaron las bobinas en los extremos del stent, las cuales también fueron modeladas mediante bocetos en 2D y extrusiones en forma de bobina. Para optimizar el proceso, se aplicó una operación de simetría que permitió duplicar la primera bobina y posicionarla en el extremo opuesto del dispositivo.

A continuación, se realizó un diseño independiente para visualizar el sensor con mayor detalle. Para su desarrollo, se utilizó un boceto en 2D que incluía todas las dimensiones necesarias para extruir de forma individual cada una de las capas que lo conforman.

Todos los parámetros utilizados en el diseño se encuentran detallados en el Anexo D; en caso de duda, los planos se encuentran disponibles en el Anexo F.

### G.1.2. Ensayos de viabilidad

Una vez obtenido el diseño del stent, se planteó realizar una serie de simulaciones mediante software gratuito para evaluar su comportamiento. Se probó el uso de ANSYS Student; sin embargo, tras la implementación de todos los parámetros y el inicio de la simulación, el equipo informático utilizado no pudo procesarla y se bloqueó. Esto reveló una limitación importante: el equipo disponible no contaba con la capacidad necesaria para ejecutar simulaciones complejas de manera eficiente.

Ante esta restricción, se consideró la utilización de simuladores 3D en línea como alternativa.Sin embargo, comprensión y manejo de las herramientas de simulación resultaron ser excesivamente complejos para la fase actual del proyecto. A pesar de estas dificultades, se llevó a cabo una simulación preliminar con un modelo simplificado, consistente en un cilindro compacto. El objetivo fue simular el comportamiento del Nitinol, un material con memoria de forma dependiente de la temperatura. No obstante, como se detalla

G.1. Cuaderno de trabajo | 35

en la sección de resultados, los resultados obtenidos no fueron satisfactorios ni representativos.

Dada esta situación, se decidió optar por un enfoque alternativo basado en modelos teóricos y aproximaciones matemáticas. Estos modelos se implementaron mediante Jupyter Notebook utilizando Python, con el fin de analizar la variación de los parámetros de diseño, permitiendo así una evaluación preliminar de la viabilidad del diseño sin requerir elevados recursos computacionales. Los ensayos modelados se encuentras a continuación.

G.1.2.1. Simulación de la expansión térmica del Nitinol

El objetivo de este análisis es evaluar cómo se comporta el stent durante el proceso de expansión térmica, teniendo en cuenta que, en la práctica clínica, este se introduce comprimido dentro de un catéter mediante un procedimiento mínimamente invasivo conocido como angioplastia. Una vez colocado en la posición deseada dentro de la arteria, el stent debe expandirse hasta alcanzar su diámetro funcional.

El material seleccionado para la base del stent es Nitinol, una aleación de níquel y titanio que presenta propiedades de memoria de forma. Esta característica permite que el material recuerde una forma predefinida y la recupere al alcanzar una temperatura específica. En concreto, el Nitinol puede estar en fase martensítica a temperatura ambiente (por ejemplo, 24°C), donde se encuentra comprimido, y transitar a fase austenítica a temperatura corporal (alrededor de 37°C), momento en el cual recupera su forma expandida.

Dado que el diseño del stent en este trabajo se ha modelado directamente en su estado expandido, se ha realizado una aproximación teórica para estimar cuáles serían las dimensiones iniciales necesarias del stent comprimido para que, al expandirse por efecto térmico, alcance las dimensiones finales deseadas. Este cálculo permite comprobar si el diseño es viable y coherente con el comportamiento del Nitinol en condiciones fisiológicas reales.

Modelo de expansión térmica del Nitinol

Para analizar la expansión térmica del stent, se ha desarrollado una aproximación matemática simplificada que permite simular el comportamiento termomecánico del material a lo largo de sus tres fases térmicas: martensita(ecuación G.1), transición de fase (ecuación G.4) y austenita (ecuación G.5). Esta modelización permite obtener una estimación del cambio dimensional del stent en función de la temperatura, considerando las propiedades específicas del Nitinol.

36 | Apéndice G. Estudio experimental
| Cabe destacar que esta aproximación no reproduce completamente el
comportamiento real del Nitinol, que incluye fenómenos más complejos como superelasticidad, histéresis térmica completa y transformaciones inducidas por tensión. No obstante, resulta válida para realizar un analisis inicial del proceso de recuperación de forma térmica, clave para la expansión pasiva del stent una vez implantado.

Consideraciones del modelo

La expansión térmica en cada fase es modelada, según el coeficiente de expansión correspondiente:

- αm: coeficiente de expansión térmica en fase martensítica.
- αa: coeficiente de expansión térmica en fase austenítica.

Durante la transición de fase (entre As y Af ), se emplea una función de fracción transformada suave basada en un coseno, inspirada en los modelos de Tanaka [15] y Shaw & Kyriakides [16], que permiten una transición continua en lugar de una evolución brusca.

Módelo matemático

El modelo calcula el longitud D(T) en función de la temperatura T siguiendo tres zonas:

1. Zona martensítica (T < As):
D(T) = D0 · (1 + αm · (T − Tmin)) | (G.1)

Se aplica la ley de expansión lineal clásica para sólidos:

∆L = L0 · α · ∆T | (G.2)
2. Zona de transición (As ≤ T ≤ Af ):

Durante esta fase, se produce una evolución gradual de la fracción transformada f(T) desde martensita a austenita. Para modelar este fenómeno se usa:

f(T) = 1
2

1 − cos

π ·

T − As
Af − As
!! | (G.3)

G.1. Cuaderno de trabajo | 37

Esta forma funcional es una aproximación realizada para suavizar la transición, inspirada en los modelos desarrollados para aleaciones con memoria de forma [15, 16].

La expansión se modela como una composición acumulativa de las expansiones en martensita y austenita, ponderada por la fracción transformada:

D(T) = D0 ·(1+αm ·(As−Tmin))·(1+αa ·(T −As))·(1+f(T)) (G.4)

En este modelo G.4:

El primer término recoge la expansión desde Tmin hasta As en fase martensita.

El segundo, desde As hasta T en fase austenita.

El tercero añade el efecto adicional de la transformación de fase (efecto no puramente térmico), reflejado en el cambio microestructural del material.

3. Zona austenítica (T > Af ):

D(T) = D0 ·(1 + αm ·(As − Tmin))·(1 + αa ·(T − As))·(1 + 1) (G.5)

Aquí se asume que la fracción transformada ha alcanzado su valor máximo (f(T) = 1). Por tanto, el diámetro final incluye:

La expansión térmica completa.

El efecto completo de la transformación a austenita.

El término adicional (1 + f(T)) tiene como objetivo representar de forma simplificada la evolución progresiva de la estructura interna del material a medida que varía la temperatura. Este incremento no se explica únicamente por la dilatación térmica clásica, sino que también incorpora los efectos de las transformaciones internas en la microestructura, como cambios de fase o reorganización atómica, que influyen en el comportamiento macroscópico del Nitinol.

La función f(T), que varía suavemente entre 0 y 1 durante la zona de transición, permite modelar esta evolución no lineal de manera continua y gradual, inspirándose en enfoques suavizados como los propuestos por Tanaka [15] y Shaw & Kyriakides [16]. Aunque estos modelos consideran la dependencia tanto de la temperatura como del esfuerzo aplicado, en esta

38 | Apéndice G. Estudio experimental

aproximación simplificada se representa únicamente la dependencia térmica para facilitar el análisis inicial.

Es importante destacar que el factor 1+f(T) no implica que la dimensión del material se duplique literalmente, sino que actúa como un multiplicador que añade un efecto adicional relativo de expansión debido a la transformación de fase, el cual debe ser calibrado para mantenerse dentro de valores físicamente razonables.

G.1.2.2. Simulación del flujo sanguíneo en el Stent

El objetivo de este análisis es evaluar el comportamiento del flujo sanguíneo a través del stent implantado en una arteria coronaria, bajo diferentes condiciones fisiológicas(reposo y actividad). Para ello, se utiliza el modelo clásico de Poiseuille, que describe el movimiento de un fluido viscoso en un conducto cilíndrico, permitiendo calcular variables como la caída de presión, el caudal volumétrico, la velocidad promedio y el perfil de velocidades a lo largo del radio del stent . Además se calculan los parámetros clínicos como el índice de reserva fraccional (FFR) y el índice de reserva instantánea (iFR).

Fundamento teórico del flujo sanguíneo

El flujo sanguíneo en arterias coronarias con stent puede aproximarse como un flujo laminar y viscoso, descrito por la ley de Poiseuille [17, 18]. Este modelo es aplicable siempre que el flujo no presente turbulencias significativas, condiciones comunes en vasos sanos o con estenosis leves.

La ecuación fundamental de Poiseuille para el caudal volumétrico Q es:

Q =

π · R⁴
- ∆P
8 · µ · L

(G.6)

donde:

Q: flujo volumétrico (m³/s)

R: radio del vaso o stent (m)

∆P: caída de presión a lo largo del stent (Pa)

µ: viscosidad dinámica de la sangre (Pa·s)

L: longitud del stent (m)

G.1. Cuaderno de trabajo | 39

De la ecuación G.6 se puede despejar la caída de presión como:

∆P =

8 · µ · L · Q
π · R⁴

(G.7)

Perfil de velocidades

Por otro lado, el perfil de velocidades dentro del stent se aproxima a un comportamiento parabólico, característico del flujo laminar en tubos rígidos. Este comportamiento surge de la solución analítica de las ecuaciones de Navier-Stokes para un fluido newtoniano en condiciones de flujo laminar estacionario y completamente desarrollado, tal como se describe en [19]. En estas condiciones, la velocidad del fluido es máxima en el centro del tubo y disminuye de forma cuadrática hacia las paredes, donde se anula debido a la condición de adherencia (no deslizamiento) del fluido a la superficie.

v(r) = vmax

1 −

r

2
R²

!
(G.8)

donde:

v(r): velocidad en una posición radial r (m/s)

vmax: velocidad máxima en el centro del stent (m/s)

R: radio interno del stent (m)

r: distancia radial desde el centro del stent (m)

La velocidad promedio (ecuación G.9) se relaciona con la máxima por:

vprom =

vmax
2

(G.9)

FFR o iFR

Finalmente, se calcularon los índices de reserva fraccional (FFR) e índice de reserva instantánea (iFR) son herramientas clínicas ampliamente utilizadas para evaluar la funcionalidad hemodinámica de arterias coronarias con estenosis y la efectividad del stent implantado [20]. Ambos se definen como la relación entre las presiones distal y proximal al stent:

40 | Apéndice G. Estudio experimental

F F R = iF R =

Pdistal

Pproximal

(G.10)

Valores cercanos a 1 indican ausencia de obstrucción significativa, mientras que valores por debajo de 0.80 sugieren un flujo restringido que podría comprometer la perfusión miocárdica.

La diferencia principal entre FFR e iFR es que el FFR se mide bajo vasodilatación inducida farmacológicamente, mientras que el iFR se evalúa en condiciones de reposo, sin necesidad de medicamentos vasodilatadores, facilitando un diagnóstico menos invasivo [20].

G.1.2.3. Simulación électrica del circuito LC

Objetivo

Este análisis presenta los fundamentos teóricos y cálculos necesarios para evaluar la viabilidad del sistema de comunicación del stent inteligente, basado en un circuito resonante LC. Se evaluarán los siguientes parámetros:

Inductancia (L) de las bobinas integradas en el stent.

Capacitancia (C) del sensor.

Frecuencia de resonancia (f) del sistema.

Factor de calidad (Q) del circuito.

Distancia máxima de comunicación mediante acoplamiento inductivo.

### 1. Cálculo de la Inductancia de las Bobinas del Stent

La inductancia es una propiedad electromagnética que cuantifica la capacidad de una bobina para inducir un campo magnético ante el paso de corriente. En este trabajo, este parámetro se calcula mediante la fórmula empírica de Wheeler[21]. Esta expresión es válida para bobinas con geometría cilíndrica corta y ancha, caracterizadas por un radio r que supera el 80 % de su longitud l, condición que cumple las bobinas utilizadas. La fórmula aplicada es:

| L(µH) = r
| 2 · N²
| 9r + 10l

(G.11)

G.1. Cuaderno de trabajo | 41

donde L es la inductancia en microhenrios, r y l son el radio y la longitud de la bobina en centímetros, respectivamente, y N es el número de vueltas.

Dado que el stent inteligente está formado por dos bobinas interconectadas en paralelo, la inductancia total Ltotal se calcula como:

1

Ltotal

=

1
L1

+

1
L2
| (G.12)

### 2. Cálculo de la Capacitancia Total del Sensor

La capacitancia es una propiedad eléctrica que mide la capacidad de un sistema para almacenar carga eléctrica cuando se aplica una diferencia de potencial. En el caso del sensor integrado en el stent, se utiliza una estructura tipo sándwich formada por dos electrodos paralelos separados por un dieléctrico. La fórmula empleada para calcular la capacitancia de un condensador plano [22, 23] es:

C = ε0 · εr ·

A
d

(G.13)

donde C es la capacitancia en faradios (F), ε0 es la permitividad del vacío (8,854 × 10⁻¹² F/m), εr es la permitividad relativa del material dieléctrico (en este caso, PDMS), A es el área de superposición entre los electrodos (en metros cuadrados), y d es la distancia entre los electrodos (espesor del dieléctrico, en metros).

En esta proyecto, las pequeñas variaciones en d (por deformación del sensor ante cambios de presión o rigidez en la pared arterial) provocan cambios en la capacitancia, lo que permite detectar y cuantificar dichas variaciones fisiológicas.

### 3. Cálculo de la frecuencia de resonacia

La frecuencia de resonancia es la frecuencia a la que oscila el circuito LC formado por la bobina y el sensor capacitivo. Esta frecuencia viene dada por la fórmula del circuito resonante[24]:

f0 =

1
2π

√
LC

(G.14)

donde f0 es la frecuencia de resonancia (en Hz), L es la inductancia de la bobina (en Henrios) y C es la capacitancia del sensor (en Faradios).

42 | Apéndice G. Estudio experimental

### 4. Factor de calidad del circuito LC

| El factor de calidad Q caracteriza la eficiencia de un circuito resonante
LC, cuantificando la relación entre la energía almacenada y la energía disipada. Un valor elevado de Q indica bajas pérdidas energéticas y una alta selectividad en la respuesta en frecuencia del sistema. Matemáticamente, se define como[24]:

Q =

1
R

·

s
L
C

(G.15)

donde R es la resistencia, L la inductancia y C la capacitancia del circuito.

Para calcular correctamente Q, es necesario determinar la resistencia total de las bobinas. La resistencia de un conductor se puede estimar mediante la expresión[25]:

R = ρ ·

l
A

(G.16)

donde ρ es la resistividad del material conductor (Ω · m), l es la longitud del hilo conductor (en metros) y A es el área de su sección transversal (en metros cuadrados).

Como el circuito cuenta con dos bobinas conectadas en paralelo, la resistencia total se calcula como:

R_total =

1
R1

+

1
R2

−1
(G.17)

### 5. Distancia máxima de comunicación

En el contexto de sistemas de transferencia inalámbrica de energía mediante acoplamiento inductivo, la distancia máxima permisible entre la bobina transmisora y la bobina receptora puede estimarse mediante la siguiente expresión[26]:

dmax = rt

·

s
Qt
- Qr

keff

(G.18)

donde radio de la bobina transmisora rt

, de los factores de calidad de la bobina transmisora Qt y de la receptora Qr, así como del coeficiente de acoplamiento efectivo keff.

G.1. Cuaderno de trabajo | 43

Su propósito es ofrecer una estimación razonable de la separación máxima admisible entre bobinas para garantizar una transferencia de energía eficiente.

G.1.2.4. Evaluación mecánica del stent

Para evaluar la integridad estructural del stent inteligente, se ha modelado inicialmente como un cilindro hueco abierto sometido a presión interna, generada por la sangre dentro del vaso, que es la carga más relevante en el funcionamiento normal del dispositivo. Aunque existen otras cargas, como la presión externa del tejido circundante y las tensiones derivadas de los movimientos vasculares o del proceso de expansión del stent, en esta sección se considerará únicamente la presión interna para simplificar el análisis.

Debido a que el cilindro está abierto en sus extremos, la presión interna genera principalmente tensiones circunferenciales y radiales en la pared del stent, mientras que la tensión axial inducida por la presión se considera despreciable, ya que no actúa sobre las caras abiertas. Otras tensiones axiales derivadas de movimientos o fuerzas externas quedan fuera del alcance de este análisis preliminar.

Se han utilizado dos modelos para el análisis: el modelo de cilindro de pared delgada y la teoría de Lame para cilindros de pared gruesa. El primero ofrece una solución simple y directa cuando el espesor es relativamente pequeño, mientras que el segundo permite analizar distribuciones de tensión más complejas cuando el espesor no puede despreciarse.

Modelo de cilindro de pared delgada

Este modelo se considera válido cuando la relación entre el espesor de la pared t y el radio interior ri del cilindro cumple con la siguiente condición:

t
ri
< 0,1 | (G.19)

Bajo esta condición, se pueden adoptan simplificaciones que facilitan el análisis sin comprometer la precisión en geometrías delgadas:

Se asume que la tensión se distribuye de manera uniforme a lo largo del espesor de la pared.

Se considera que la tensión radial es muy pequeña en comparación con la tensión circunferencial, por lo que se desprecia.

44 | Apéndice G. Estudio experimental

Estas suposiciones son razonables porque, en estructuras con paredes delgadas, las tensiones no varían significativamente desde la cara interna hasta la externa. Por tanto, el esfuerzo puede considerarse constante a través del espesor, lo cual simplifica los cálculos y permite una evaluación preliminar eficaz, especialmente útil durante la fase de diseño.

La tensión circunferencial, también denominada tensión tangencial o “hoop stress”, se expresa como [27, 28]:

σθ =

p · ri
t

(G.20)

La tensión radial, al ser no significativa en este modelo, se aproxima a:

σr ≈ 0 | (G.21)

Dado que la tensión circunferencial es dominante, la tensión equivalente de Von Mises, utilizada para estimar el criterio de fallo, se aproxima simplemente como:

σvm ≈ σθ | (G.22)

Las variables utilizadas son:

σθ: tensión circunferencial o tangencial (Pa)

σr: tensión radial (Pa)

σvm: tensión equivalente de von Mises (Pa)

p: presión interna aplicada (Pa)

ri

: radio interior del cilindro (m)

t = ro − ri

: espesor de la pared (m)

Modelo de cilindro de pared gruesa (Teoría de Lame)

Cuando el espesor de la pared no puede considerarse despreciable en comparación con el radio interior, es decir,

t
ri
≥ 0,1 | (G.23)

G.1. Cuaderno de trabajo | 45

la distribución de tensiones a lo largo del espesor ya no puede asumirse uniforme. En este caso, se aplica la teoría de Lame para cilindros de pared gruesa, que permite obtener expresiones más precisas para las tensiones radial y circunferencial como función del radio r, considerando tanto la presión interna Pi como la presión externa Po [29] :

σr(r) = Pir

2
i − Por

2
o
r

2

o − r

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
(Po − Pi)
(r
2

o − r

2
i

)r
2

(G.24)

σθ(r) = Pir

2
i − Por

2
o
r

2

o − r

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
(Po − Pi)
(r
2

o − r

2
i

)r
2

(G.25)

A partir de estas tensiones, la tensión equivalente de Von Mises puede calcularse como[28]:

σvm(r) = s
1
2

[(σθ(r) − σr(r))² + σθ(r)

2 + σr(r)
2
] | (G.26)

Este modelo es más complejo desde el punto de vista matemático y computacional, pero proporciona una representación más precisa del estado tensional en estructuras donde el espesor tiene una influencia considerable.

Aplicación al stent inteligente

Los stents coronarios tradicionales presentan paredes delgadas en comparación con su radio interior, lo que justifica el uso del modelo de cilindro de pared delgada para una primera aproximación. Esta simplificación permite analizar de forma eficiente las tensiones inducidas por la presión sanguínea interna.

Sin embargo, en el caso del stent inteligente, es posible que el diseño incluya elementos adicionales como sensores, recubrimientos o refuerzos estructurales que incrementen el espesor efectivo de la pared. En tales situaciones, el uso exclusivo del modelo de pared delgada podría no ser suficiente, y sería necesario recurrir a la teoría de Lame para evaluar con mayor precisión la distribución real de tensiones y garantizar la integridad mecánica del dispositivo bajo distintas condiciones de operación.

Por tanto, la elección entre uno u otro modelo depende directamente de la geometría final del stent.

Evaluación de Seguridad

46 | Apéndice G. Estudio experimental
| Para evaluar si el material trabaja dentro de condiciones seguras, se
utiliza el criterio de von Mises junto con un factor de seguridad. La condición de seguridad se expresa mediante [30]:

σvm <

σlímite
F S | (G.27)

Donde:

σvm: tensión equivalente de Von Mises calculada (en Pa),

σlímite: límite elástico del material.

F S: factor de seguridad utilizado.

Una vez obtenida la tensión de von Mises a partir del análisis de esfuerzos, se compara con el valor límite ajustado por el factor de seguridad. Si se cumple la condición anterior, se considera que el diseño es seguro bajo las condiciones de carga evaluadas.

## G.2. Configuración y parametrización de las

técnicas.

### G.2.1. Parámetrización de ensayo de expansión de Nitinol

Parámetro | Valor
Tipo de medida | longitud / diámetro
Valor inicial (mm) | 10,40 / 1,8
Temperatura mínima (°C) | 18
Temperatura máxima (°C) | 50
As (°C) | 24,00
Af (°C) | 40,00
αm (°C

−1

) | 6,6 × 10⁻⁶
αa (°C

−1

) | 11 × 10⁻⁶

Tabla G.1: Configuración de la expansión del Nitinol

Explicación de los parámetros de la TablaG.1:

G.2. Configuración y parametrización de las técnicas. | 47

Tipo de medida: Indica si la dimensión a analizar es la longitud o el diámetro del stent o componente. Ambas dimensiones pueden verse afectadas por la expansión térmica.

Valor inicial (mm): Corresponde a la dimensión inicial de referencia, antes de cualquier expansión térmica. Se proporcionan valores tanto para la longitud como para el diámetro. En este caso, se han seleccionado valores óptimos para asegurar una correcta implantación del dispositivo.

Temperatura mínima y máxima (°C): Intervalo de temperaturas en el que se lleva a cabo el análisis térmico del material.

As (Temperatura de inicio de austenita, °C): Temperatura a la que comienza la transformación de la fase martensita a austenita durante el calentamiento. Se ha elegido un valor de 24°C, ligeramente superior a la temperatura ambiente típica de quirófano (aproximadamente 21°C), para reflejar condiciones realistas de activación.

Af (Temperatura de finalización de austenita, °C): Temperatura a la que se completa la transformación a la fase austenita. Se ha establecido en 50°C para abarcar un rango amplio de condiciones, incluyendo la temperatura corporal normal (37°C), fiebre leve y escenarios de calentamiento experimental, garantizando así que se observe el cambio completo de fase del Nitinol.

αm (Coeficiente de expansión térmica en fase martensita, °C⁻¹
): Indica cuánto se expande el material por cada grado Celsius en la fase martensita, caracterizada por ser más dúctil. [31]

αa (Coeficiente de expansión térmica en fase austenita, °C⁻¹ ):
Representa la expansión térmica por grado Celsius en la fase austenita, generalmente más rígida y con un coeficiente mayor que αm. [31]

### G.2.2. Parámetrización del ensayo de flujo sanguíneo

Explicación de los parámetros de la Tabla G.2):

µ (Pa·s): Viscosidad dinámica de la sangre, que representa la resistencia interna al flujo. Su valor típico es del orden de 10⁻³ Pa·s [32].

48 | Apéndice G. Estudio experimental
Parámetro | Valor
µ (Pa·s) | 3,5 × 10⁻³
L (m) | 0,0020
Q (m³/s) | 3,33 × 10⁻⁶ / 16,67 × 10⁻⁶
Rstent (m) | 1,775 × 10⁻³
Pentrada (Pa) | 13 332

Tabla G.2: Parámetros utilizados para el análisis del flujo sanguíneo en el interior del stent.

L (m): Longitud del stent, es decir, el tramo del vaso sanguíneo que se analiza.

Q (m³/s): Caudal volumétrico de sangre que atraviesa el stent por segundo. Este parámetro varía significativamente en función del estado fisiológico del paciente. En condiciones de reposo se ha considerado un valor de 3,33 × 10⁻⁶ m³/s (equivalente a 200 mL/min), mientras que durante la actividad física puede aumentar notablemente, alcanzando hasta 16,67 × 10⁻⁶ m³/s (equivalente a 1.000 mL/min), valor que se ha incluido para evaluar el comportamiento del sistema en condiciones exigentes [33].

Rstent (m): Radio interno del stent, equivalente al radio del vaso tratado.

Pentrada (Pa): Presión en el extremo de entrada del stent, que impulsa el flujo.

Pentrada (Pa): Presión en el extremo de entrada del stent, que impulsa el flujo sanguíneo. En condiciones fisiológicas normales, la presión arterial suele oscilar entre 70 y 110 mmHg. Para este análisis, se ha seleccionado el valor máximo (110 mmHg), correspondiente a 13 332 Pa, con el objetivo de evaluar el comportamiento del sistema en condiciones de máxima presión.[34]

### G.2.3. Parámetrización de la simulación eléctrica del circuito LC

G.2.3.1. Cálculo de la inductancia: bobina del stent

Explicación de los parámetros de la Tabla G.3:

G.2. Configuración y parametrización de las técnicas. | 49
Parámetro | Valor

rbobina_stent (cm) 0,06

lbobina_stent (cm) 0,25
N (vueltas) | 10

Tabla G.3: Parámetros geométricos utilizados para el cálculo de la inductancia de la bobina integrada en el stent.

rbobina_stent (cm): Radio medio de las bobinas integradas en el stent.

lbobina_stent (cm): Longitud total de la bobina cilíndrica formada sobre el stent.

N (vueltas): Número total de espiras que conforman la bobina.

G.2.3.2. | Cálculo de la capacitancia: sensor capacitivo
Parámetro | Valor

Aelectrodo (m²

) | 1,05 × 10⁻⁷
dpoliimida (m) | 5 × 10⁻⁶
Número de pares de electrodos 48
ε0 (F/m) | 8,854 × 10⁻¹²
εp | 3,5

Tabla G.4: Parámetros utilizados para el cálculo de la capacitancia total del sensor capacitivo.

Explicación de los parámetros de la Tabla G.4:

Aelectrodo (m²

): Área de cada electrodo interdigitados, calculada según el diseño realizado.

dpoliimida (m): Espesor de la capa dieléctrica de poliimida (PI) que separa los electrodos y determina la distancia entre ellos.

Número de pares de electrodos: Total de elementos capacitivos conectados en paralelo en la estructura interdigitada del sensor. Cada par contribuye linealmente a la capacitancia total.

ε0 (F/m): Permitividad eléctrica del vacío[35].

50 | Apéndice G. Estudio experimental

εr: Permitividad relativa de la poliamida, que representa la capacidad del material dieléctrico para almacenar carga eléctrica en comparación con el vacío. [36]

G.2.3.3. Cálculo de la frecuencia de resonancia: circuito LC

Parámetro Valor

Ltotal (H) | 0,06 µH = 6,0 × 10⁻⁸
Ctotal (F) | 62,47 pF = 6,247 × 10⁻¹¹ F

Tabla G.5: Parámetros utilizados en el cálculo de la frecuencia de resonancia del circuito LC.

Explicación de los parámetros de la Tabla G.5:

Ltotal : Inductancia total del sistema. Aunque cada bobina del stent tiene una inductancia de 0,12 µH, la inductancia total combinada a 0,06 µH debido a su disposición en paralelo en el circuito .

Ctotal: Capacitancia total del sensor capacitivo, correspondiente a 48 pares de electrodos interdigitados.

G.2.3.4. | Cálculo del factor de calidad Q del circuito LC
Parámetro | Valor
ρoro Ω·m | 2,44 × 10⁻⁸
Radio de la bobina (m) | 0,0006
Número de vueltas | 10
Longitud total del hilo (m) | 0,0377
Diámetro del hilo (m) | 1 × 10⁻⁵
Área de sección transversal (m²
) 7,85 × 10⁻¹¹
Resistencia del hilo (Ω) | 5,86
Frecuencia de resonancia ( MHz) 82,75
Inductancia total (H) | 6,0 × 10⁻⁸

Tabla G.6: Parámetros utilizados en el cálculo de la resistencia de la bobina y el factor de calidad Q.

Explicación de los parámetros de la Tabla G.6:

G.2. Configuración y parametrización de las técnicas. | 51

ρoro (Ω·m): Resistividad eléctrica del oro [37].

r (m): Radio de la bobina. Este valor se utiliza para calcular la longitud del hilo conductor enrollado en forma de espira circular.

N: Número de vueltas de la bobina.

l (m): Longitud total del hilo.

d (m): Diámetro del hilo conductor.

A (m²

): Área de la sección transversal del hilo.

R (Ω): Resistencia total del hilo conductor.

f (Hz): Frecuencia de resonancia del circuito LC.

L (H): Inductancia total del circuito.

G.2.3.5. | Cálculo de la distancia máxima de comunicación
Parámetro | Valor
Lexterna (H) | 4 × 10⁻⁶
Rexterna (Ω) | 25
Cexterna (F) | 9,25 × 10⁻¹³
rt (m) | 0.035
Eficiencia de acoplamiento (keff) | 0.8
Factor de calidad del circuito interno 5.26

Tabla G.7: Parámetros de la bobina externa utilizada para la transmisión de energía y señal.

Explicación de los parámetros de la Tabla ??:

Lexterna: Inductancia de la bobina emisora externa. Se ha fijado en 4 µH, adecuada para resonar con el stent en la misma frecuencia.

Rexterna : Resistencia del circuito externo. Se estima en 25 Ω.

Cexterna (F): Capacitancia necesaria para que la bobina externa también resuene en la frecuencia deseada.

keff: Eficiencia de acoplamiento magnético. Un valor de 0.8 representa un acoplamiento eficiente en condiciones óptimas.

52 | Apéndice G. Estudio experimental

rt (m): Radio de la bobina localizada en parche externo. Se ha fijado en 3.5 cm, tamaño razonable para su uso.

G.2.4. | Parámetrización de la evaluación mécanica
Parámetro | Valor
Pentrada (Pa) | 13,032.65 (reposo) / 13,272.02 (actividad)
Radio interno del stent (m) 1,67 × 10⁻³
Radio externo del stent (m) 1,78 × 10⁻³
Espesor de la pared (m) | 0,11 × 10⁻³
σelástico(MPa) | 500 × 10⁶
Factor de seguridad (FS) | 2

Tabla G.8: Parámetros utilizados para calcular la distancia máxima.

Presión interna aplicada (Pentrada): Variable que representa la presión sanguínea en el extremo del stent. Para evaluar distintas condiciones, se consideran dos valores calculados en el ensayo de flujo:

- Reposo: 13 032,65 Pa.
- Actividad: 13 272,02 Pa.

Radio interno (ri): Radio interno del stent expandido.

Radio externo (ro): Radio total del stent considerando el espesor del hilo.

Espesor de la pared: Diferencia entre radio externo e interno, que representa el grosor del hilo del stent.

Límite elástico de la austenita (σelástico): Límite máximo de esfuerzo antes de que ocurra deformación plástica en la fase austenítica del Nitinol, con un valor de 500 × 10⁶ Pa (500 MPa)[38].

Factor de seguridad (FS): Coeficiente utilizado para garantizar que las tensiones en el material se mantengan dentro de un margen seguro, evitando fallos estructurales o deformaciones plásticas. Se ha adoptado un valor de F S = 2, con el objetivo de asegurar un funcionamiento fiable incluso ante cargas inesperadas o variabilidad en las condiciones fisiológicas.

G.3. Detalle de resultados. | 53
G.3. | Detalle de resultados.
G.3.1. | Diseño y prueba inicial de simulación

El diseño final del prototipo del stent inteligente puede observarse en la figura G.1. Una vez definido el diseño, se procedió a intentar simular su comportamiento en diferentes condiciones mediante programas de simulación por elementos finitos (FEM). A pesar de los esfuerzos realizados, se


Figura G.1: Diseño del stent inteligente final. Fuente Propia

encontraron diversas limitaciones técnicas. Uno de los resultados obtenidos se presenta en la figura G.6, donde se observa que el stent aproximado como un cilindro se expande, pero manteniendo la temperatura constante. Por tanto, este resultado no puede considerarse válido para el análisis de expansión térmica, y fue precisamente por ello que se decidió abordar el estudio mediante aproximaciones teóricas.

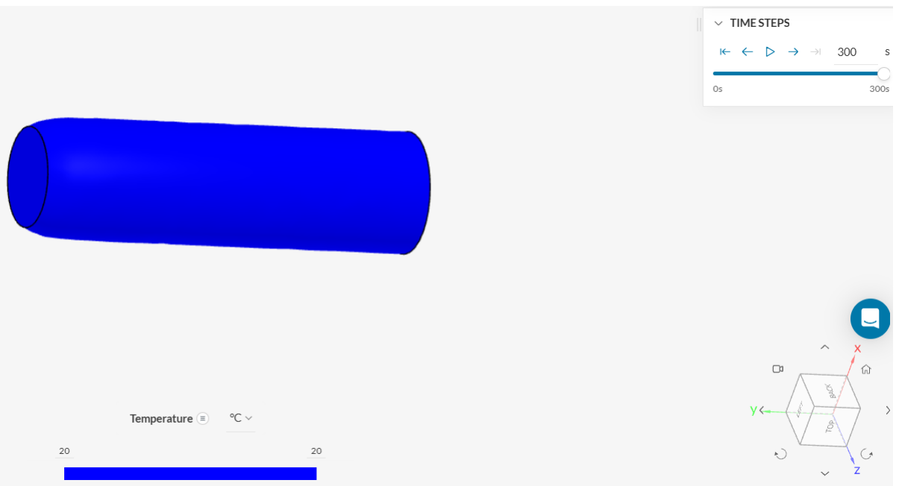
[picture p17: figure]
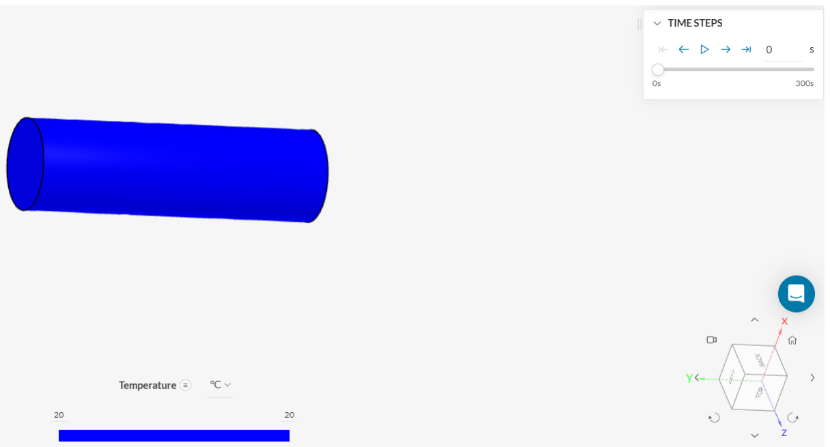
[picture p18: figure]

(a) (b)

Figura G.2: Inicio de la simulación de la expansión del Nitinol (a) y Fin de la expansión del Nitinol. Fuente Propia.

54 | Apéndice G. Estudio experimental
G.3.2. | Simulación de la expansión térmica del Nitinol

A través del modelo matemático implementado, se simuló la evolución tanto del diámetro como de la longitud del stent desde una temperatura mínima hasta temperaturas fisiológicas (alrededor de 37 ◦C). Los resultados indican que a 37 ◦C temperatura corporal—el stent alcanza un diámetro de 3,4472 mm y una longitud de 19,1510 mm.

Las gráficas obtenidas muestran una aproximación del comportamiento característico del Nitinol con memoria de forma. En ambas curvas (diámetro y longitud), se observa una primera fase de expansión muy lenta a bajas temperaturas (fase martensítica), seguida por una fase de transición acelerada (entre 24 ◦C y 40 ◦C) donde el material cambia de estructura cristalina hacia la fase austenítica, provocando un incremento rápido de las dimensiones. Finalmente, se alcanza una zona de estabilización donde el material ya se encuentra completamente transformado y la expansión se ralentiza, estabilizándose en un valor máximo.

Estas dimensiones simuladas se comparan con las especificaciones de diseño del prototipo expandido, las cuales establecen un diámetro de 3,55 mm y una longitud de 20 mm. Se observa así una diferencia de aproximadamente menor del 5 %. Estas diferencias se consideran aceptables para el modelo de simulación térmica, y no comprometen el correcto funcionamiento del stent en condiciones fisiológicas.

En consecuencia, se concluye que el comportamiento del material es coherente con lo esperado, permitiendo una validando inicial tanto el diseño como la funcionalidad térmica del prototipo inteligente.

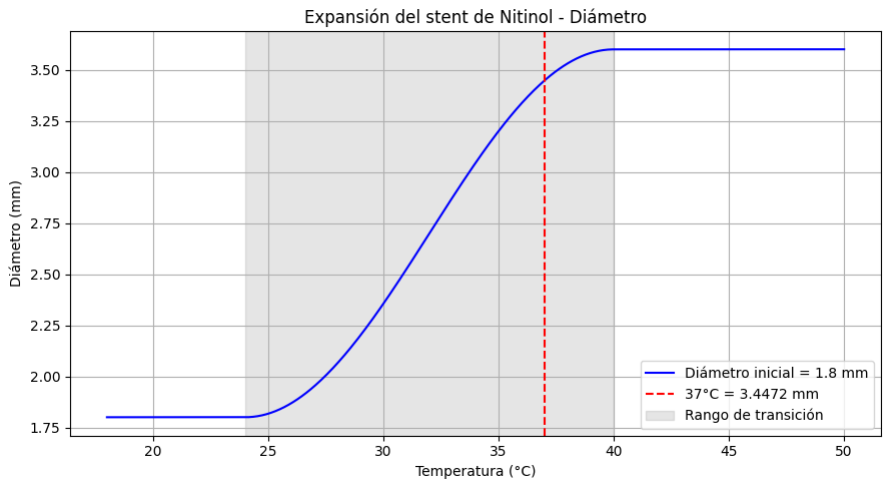
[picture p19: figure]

Figura G.3: Simulación de la expansión térmica del diámetro del stent de Nitinol Fuente Propia.

G.3. Detalle de resultados. | 55

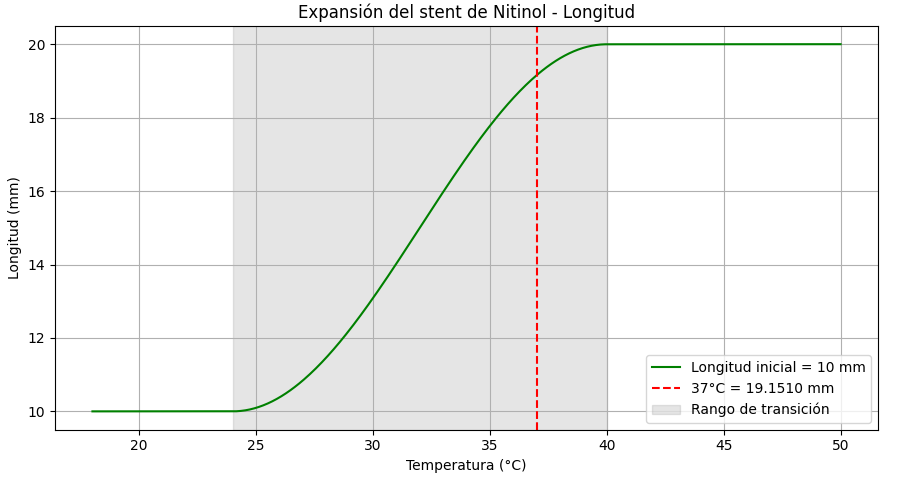
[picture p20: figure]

Figura G.4: Simulación de la expansión térmica de la longitud del stent de Nitinol. Fuente propia

### G.3.3. Simulación del flujo sanguíneo en el stent

El estudio hemodinámico del stent bajo condiciones de reposo (Figura G.6) y de actividad física (FiguraG.5) muestra un comportamiento funcional óptimo en ambos escenarios, lo cual valida el diseño del dispositivo desde un punto de vista fisiológico y clínico. En reposo, el perfil de velocidad obtenido muestra la velocidad máxima alcanza un valor de 0.673 m/s en el centro del stent, y disminuye hasta anularse en las paredes. Este comportamiento es característico de un flujo laminar plenamente desarrollado, lo que sugiere una circulación estable y eficiente, sin presencia de turbulencias ni gradientes anómalos de velocidad. La velocidad promedio del flujo se sitúa en 0.336 m/s, coherente con los valores esperados para una arteria coronaria en condiciones de reposo[39].

Cuando se analiza el comportamiento del flujo en condiciones de actividad física, se observa un incremento en las velocidades. La velocidad máxima asciende hasta aproximadamente 3.36 m/s, con una velocidad promedio igualmente elevada, lo cual es fisiológicamente acorde con el aumento del gasto cardíaco. A pesar de este incremento, el perfil de velocidad mantiene su forma parabólica, indicando que el flujo sigue siendo laminar y controlado. Esta capacidad de adaptarse a diferentes niveles de demanda sin comprometer la estabilidad del flujo es fundamental en dispositivos implantables como los stents.

La caída de presión a lo largo del stent es baja tanto en reposo como en actividad, lo cual indica que el stent no genera una resistencia significativa al paso del flujo. En ambos casos, la presión en la salida del stent permanece elevada, lo que garantiza una aporte óptimo de sangre en el territorio coro-

56 | Apéndice G. Estudio experimental

nario. Un aspecto especialmente relevante es el índice de reserva fraccional de flujo (FFR), que en ambos casos se mantiene cercano a 1.00. Este valor representa es indicativo de que el stent no produce una obstrucción fisiológica significativa.

| En conjunto, los resultados permiten concluir que el diseño del stent es
eficaz para mantener un flujo sanguíneo adecuado en condiciones de reposo y de actividad física.

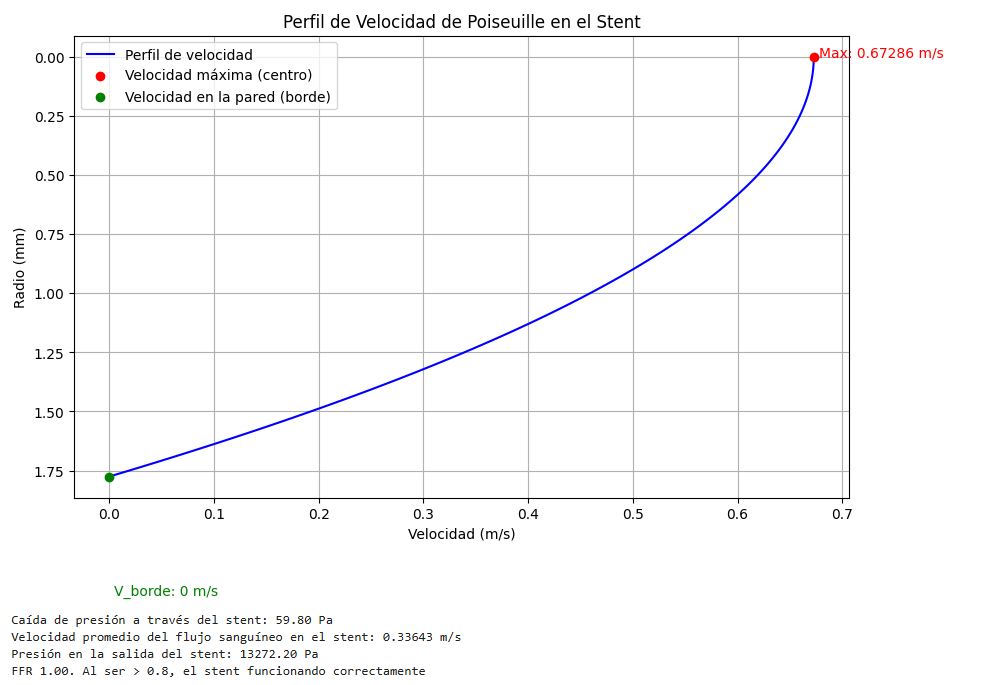
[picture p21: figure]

Figura G.5: Perfil de velocidad en reposo. Fuente Propia.

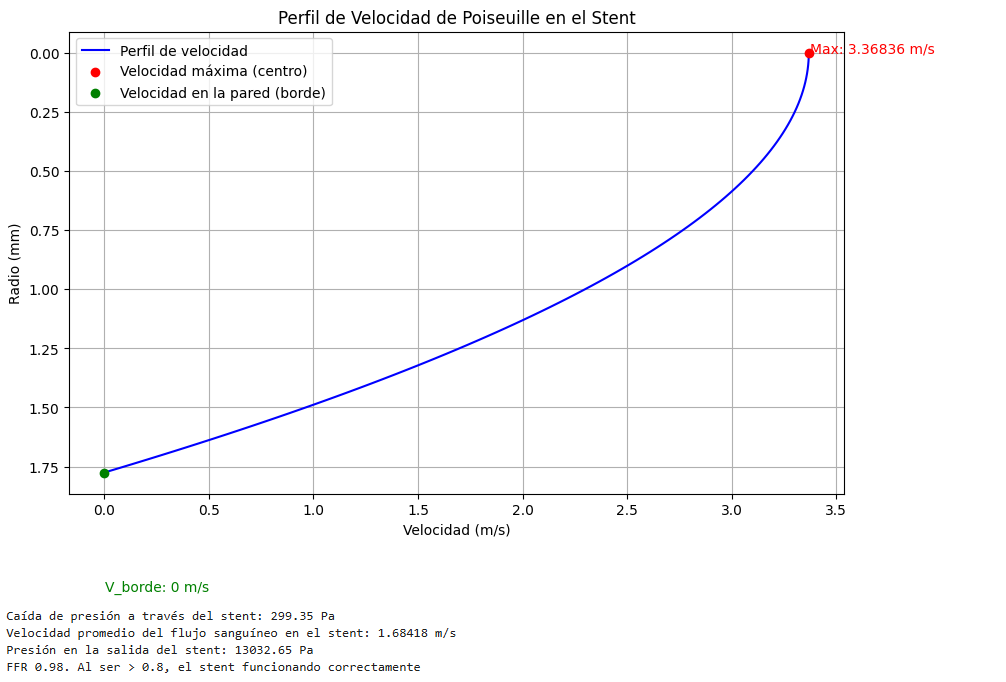
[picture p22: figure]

Figura G.6: Perfil de velocidad en actividad. Fuente propia.

G.3. Detalle de resultados. | 57

Evaluación de la estenosis en el stent

Tras ello, se ha estudiado cómo afecta una oclusión en el interior del stent (Figura G.7), evaluando condiciones de 0 % de oclusión (azul), 25 % (naranja), 50 % (rojo) y 75 % (morado). Los resultados obtenidos permiten comparar cómo distintos grados de obstrucción arterial modifican el perfil de velocidad del flujo sanguíneo y los valores de FFR/iFR, tanto en condiciones de reposo como durante la actividad física.

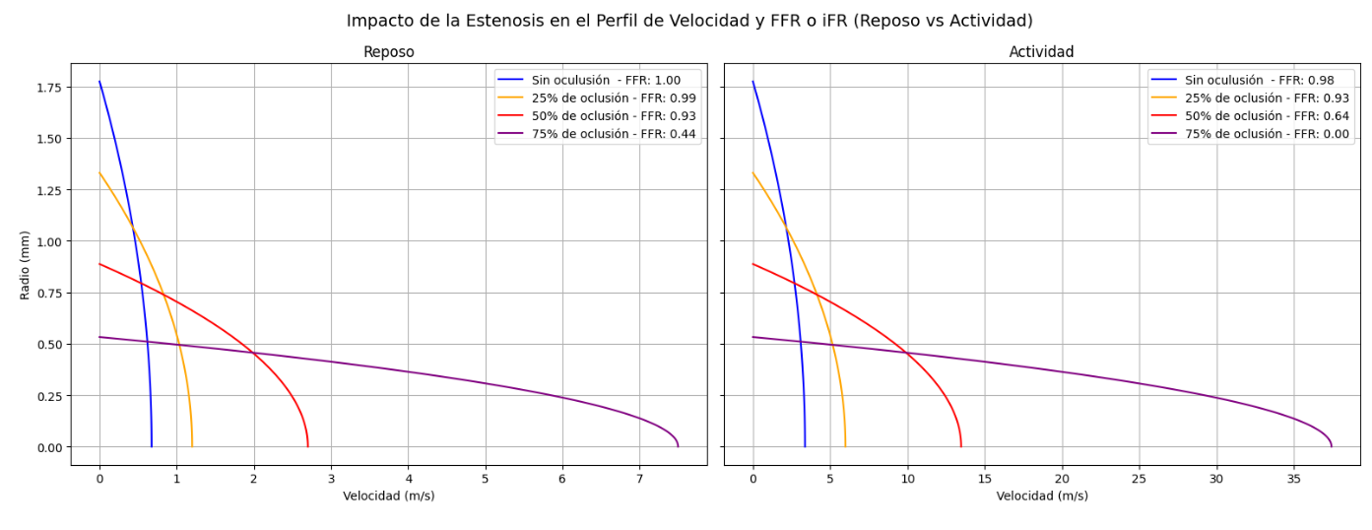
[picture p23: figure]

Figura G.7: Impacto de la estenosis en el stent. Fuente Propia.

En reposo, se observa que el perfil de velocidad aumenta progresivamente a medida que disminuye el radio del vaso. Sin embargo, hasta un 50 % de oclusión, los valores de FFR se mantienen dentro de rangos funcionales (superiores a 0.80), indicando que el flujo coronario es aún adecuado. Al alcanzar un 75 % de oclusión, el FFR desciende a 0.44, reflejando una caída significativa en la presión distal y una afectación hemodinámicamente significativa, con riesgo de isquemia grave.

Durante la actividad física, el impacto de la estenosis se intensifica. Las velocidades de flujo aumentan considerablemente, especialmente en los grados más severos de obstrucción, debido a la disminución del radio del vaso. Esta situación provoca una caída más rápida del FFR. A partir de un 50 % de oclusión, el valor de FFR desciende a 0.64, lo cual ya compromete la perfusión tisular adecuada y puede provocar isquemia del miocardio. Con un 75 % de oclusión, el FFR alcanza un valor de 0.00, indicando un necrosis del tejido cardíaco.

En conclusión, el stent inteligente propuesto demuestra ser seguro hasta con un 50 % de oclusión en condiciones de reposo, manteniendo un flujo coronario funcional. Sin embargo, durante la actividad física, ese mismo grado de oclusión genera un descenso significativo del FFR, lo que incrementa

58 | Apéndice G. Estudio experimental

el riesgo de isquemia miocárdica. Gracias a la incorporación de sensores y reguladores, este dispositivo es capaz de detectar en tiempo real las variaciones en presión y flujo permitiendo la anticipación a la aparición de riesgo isquémico.

G.3.4. | Simulación électrica del circuito LC
G.3.4.1. | 1. Cálculo de la Inductancia de las Bobinas del Stent

Los valores obtenidos son :

Inductancia de cada bobina: 0.12µH

Inductancia de total del circuito: 0.06µH

Los resultados obtenidos son coherentes con los valores esperados para dispositivos médicos, y se encuentran en el mismo orden de magnitud que los reportados en el articulo [40], aunque ligeramente por debajo. Esta diferencia es razonable, ya que el sistema descrito en dicho estudio está compuesto por múltiples bobinas, lo que incrementa la inductancia total.

Además, al conectar dos bobinas idénticas en paralelo, la inductancia total se reduce a la mitad del valor individual, resultando en una inductancia total de 0.06 µH. Este valor se considera adecuado para la escala y configuración del sistema analizado, y refleja una aproximación realista en el contexto del diseño de dispositivos implantables.

G.3.4.2. Cálculo de la Capacitancia Total del Sensor

La capacitancia total calculada para el sensor con 48 pares de electrodos es aproximadamente 62.47 pF. Este valor es razonable considerando las dimensiones del electrodo y el espesor del dieléctrico (poliimida), ya que la capacitancia en un capacitor plano depende directamente del área del electrodo y de la permitividad relativa del material dieléctrico, e inversamente proporcional a la distancia entre placas.

En dispositivos microfabricados y sensores implantables, los valores de capacitancia suelen encontrarse en el rango de picofaradios a algunos cientos de picofaradios, debido a las limitaciones de tamaño y separación de las estructuras. Esto es coherente con el resultado obtenido, que refleja una capacidad eléctrica compatible con el diseño y materiales utilizados.

G.3. Detalle de resultados. | 59
G.3.4.3. | Cálculo de la frecuencia de resonacia

La frecuencia de resonancia calculada para el circuito LC del stent es de 82.75 MHz. Esta frecuencia está dentro del rango utilizado en dispositivos médicos implantables, buscando un equilibrio entre tamaño compacto, eficiencia en la transferencia inalámbrica y penetración en tejidos biológicos. Sin embargo, la literatura indica que un valor óptimo suele estar cerca de 13.56 MHz [40], ya que mejora la penetración y reduce la absorción en tejidos. Por ello, uno de los principales objetivos futuros será ajustar el diseño para acercar la frecuencia de resonancia a este valor.

Análisis de la variación de la frecuencia en función a la capacitancia

En el sistema diseñado, la inductancia de las bobinas se mantiene constante, mientras que la capacitancia varía en función de la distancia entre los electrodos la cual a su vez se ve modificada por los eventos fisiológicos que ocurren en el interior de la arteria.

Por ello, se ha decidio analizar la frecuencia de resonancia en función de la distancia entre electrodos y la frecuencia de resonancia respecto a la capacitancia total del sistema. Ambos gráficos muestran comportamientos no lineales, de acuerdo en sistemas resonantes (Figura G.8).

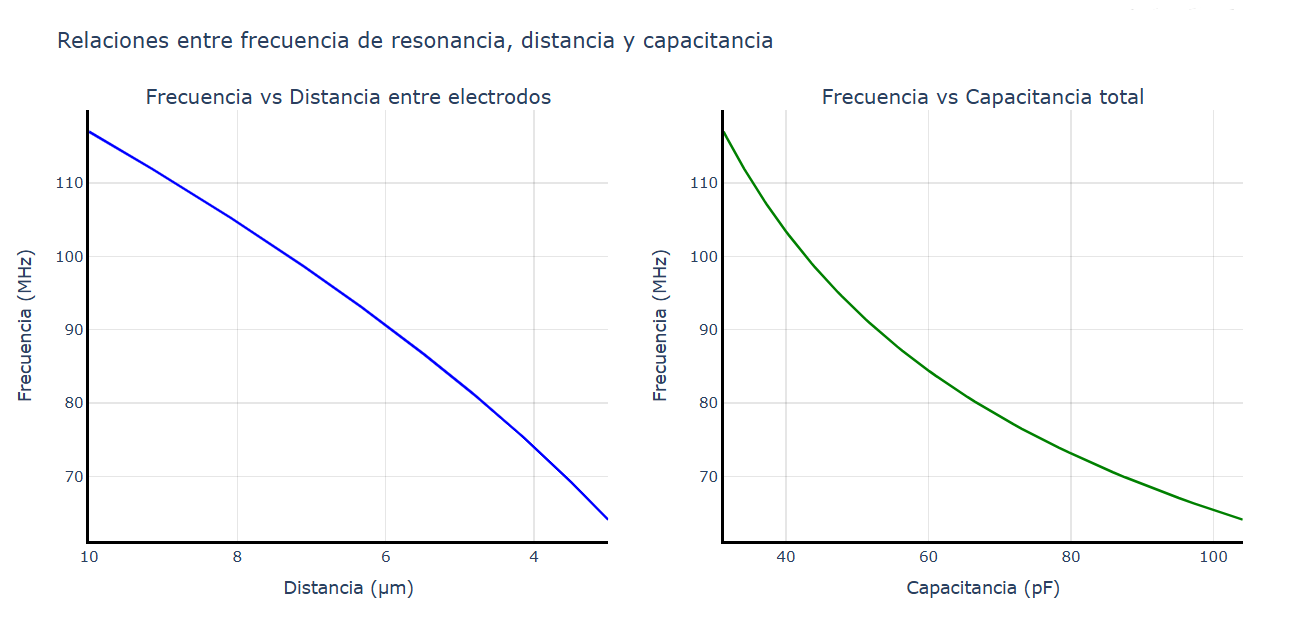
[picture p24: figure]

Figura G.8: Analisis de variación de la frecuencia. Fuente Propia.

En la primera gráfica, que representa la frecuencia de resonancia frente a la distancia entre electrodos, se observa una tendencia creciente: a medida que la distancia aumenta, también lo hace la frecuencia. Esta variación es más pronunciada en rangos de distancia reducidos, lo que indica una mayor sensibilidad del sistema ante pequeños cambios en dicho parámetro.

60 | Apéndice G. Estudio experimental

La segunda gráfica, correspondiente a la frecuencia en función de la capacitancia total, revela una relación inversamente proporcional. A medida que la capacitancia aumenta, la frecuencia disminuye de forma significativa. La curva presenta una pendiente más marcada en los valores bajos de capacitancia, lo que sugiere que el sistema es más sensible a pequeñas variaciones en ese rango.

G.3.4.4. Factor de calidad del circuito LC

El factor de calidad calculado del circuito LC es Q = 5.26, un valor relativamente bajo en comparación con circuitos ideales, debido principalmente a la resistencia del hilo de oro y las limitaciones de tamaño y materiales propias de dispositivos miniaturizados.

Sin embargo, en dispositivos médicos implantables, este valor es considerado bueno y adecuado, ya que cumple con las restricciones físicas y de biocompatibilidad. De hecho, según el estudio de Ghaed et al. (Universidad de Michigan) [41], un Q cercano a 4.9 es aceptado en microsistemas biomédicos implantables, lo que muestra la validez del resultado obtenido en este proyecto para el sistema de comunicación del stent inteligente.

G.3.4.5. Distancia máxima de comunicación

El factor de calidad calculado para el circuito externo es Q = 83.19, un valor elevado que indica una resonancia bien definida y bajas pérdidas resistivas en el circuito. Esto contribuye a una transferencia de energía eficiente y una mayor sensibilidad en la comunicación inductiva con el stent inteligente.

La distancia máxima de comunicación estimada es de 0.59 metros, un valor suficiente para la lectura no invasiva del dispositivo implantado mediante un parche o dispositivo externo posicionado sobre la piel próxima al implante. En la práctica, la distancia de operación será menor que el valor máximo calculado permitiendo una comunicación robusta.

Estos resultados confirman que el diseño del circuito externo es adecuado para establecer una comunicación inductiva efectiva y estable con el circuito interno del stent.

### G.3.5. Evaluación mecánica del stent

Se llevó a cabo un análisis mecánico del stent utilizando la teoría del cilindro delgado, dado que la relación entre el espesor de la pared y el radio

G.3. Detalle de resultados. | 61

interno cumple con los criterios que justifican este modelo. Este enfoque permite estimar de manera confiable las tensiones generadas en la estructura como consecuencia de la presión interna ejercida por el fluido.

Las presiones consideradas en este análisis fueron obtenidas a partir del estudio previo de flujo, lo que garantiza que las condiciones evaluadas reflejan escenarios fisiológicos realistas tanto en reposo como durante la actividad.

Bajo condiciones de reposo, Figura G.9, el stent fue sometido a una presión interna que generó una tensión circunferencial de aproximadamente 0.208 MPa. Esta tensión representa el esfuerzo que actúa alrededor del perímetro del dispositivo. En este estado, la tensión radial es despreciable, y la tensión equivalente, también conocida como tensión de von Mises, presenta el mismo valor: 0.208 MPa.

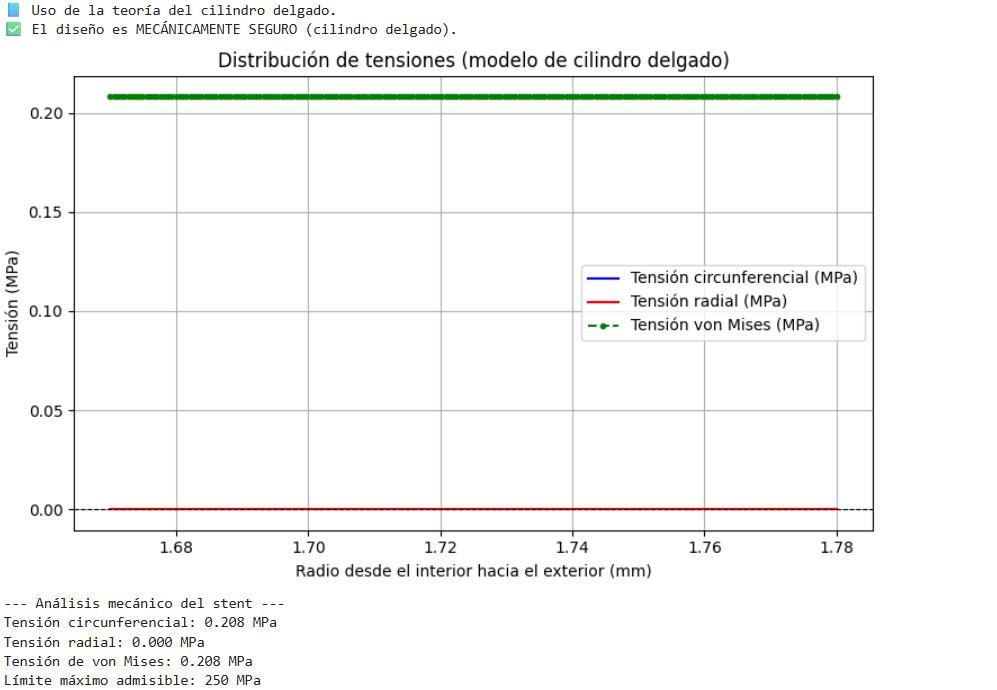
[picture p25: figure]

Figura G.9: Variación de las tensiones en reposo. Fuente Propia.

En condiciones de actividad,Figura G.10, cuando la presión interna disminuye ligeramente, se observa una leve reducción en las tensiones. La tensión circunferencial y la tensión de von Mises descienden a un valor de 0.204 MPa. Cabe destacar que la menor presión observada durante la actividad se debe al aumento de la velocidad del flujo, lo cual, reduce la presión estática en el interior del stent. Esta pequeña variación no compromete la integridad estructural del dispositivo, lo que indica un comportamiento mecánico estable frente a los cambios fisiológicos.

62 | Apéndice G. Estudio experimental

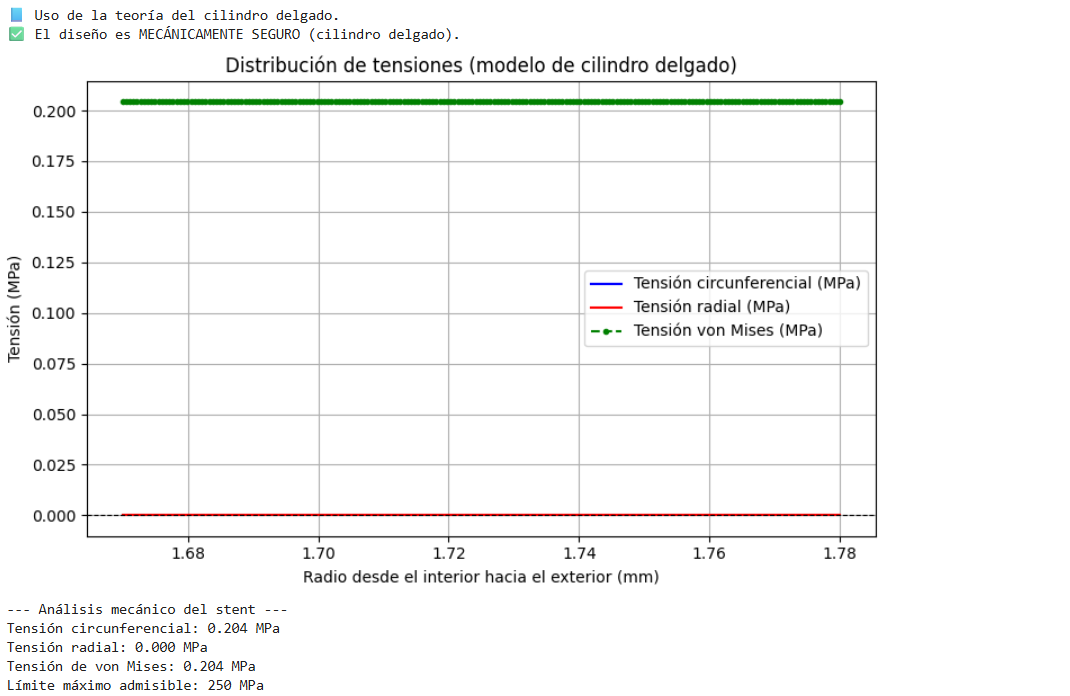
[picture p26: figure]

Figura G.10: Variación de las tensiones en reposo. Fuente Propia.

Para evaluar la seguridad del diseño, se consideró un factor de seguridad de 2, lo que implica que el límite máximo admisible para el material es de 250 MPa. Las tensiones obtenidas en ambas condiciones están muy por debajo de este valor, lo que garantiza un amplio margen de seguridad y una baja probabilidad de falla mecánica.

La distribución de tensiones a lo largo del espesor del stent se mantiene constante, ya que es uno de los criterios del modelo de cilindro delgado.

En conclusión, los resultados obtenidos demuestran que el diseño del stent es mecánicamente seguro tanto en reposo como en actividad, permitiendo un funcionamiento óptimo en condiciones fisiológicas normales.

## Apéndice H

# Anexo de sostenibilización curricular

## H.1. Introducción

Este anexo presenta una reflexión sobre los aspectos de sostenibilidad abordados en el Trabajo Fin de Grado titulado “Diseño de un stent inteligente basado en reguladores”. En el contexto de la Ingeniería de la Salud, la sostenibilidad no solo se refiere al respeto por el medio ambiente, sino también a la integración ética, eficiente y responsable de tecnologías aplicadas a la mejora de la salud y el bienestar de las personas.

El trabajo se localiza dentro de un enfoque interdisciplinar que une el conocimiento técnico con los principios de salud pública, fomentando un desarrollo tecnológico que no solo sea viable a nivel funcional, sino también sostenible desde el punto de vista ambiental, social y económico.

## H.2. Sostenibilidad aplicada a la Ingeniería de la Salud

La sostenibilidad en el ámbito sanitario implica garantizar la eficacia de los tratamientos, reducir el impacto ambiental y optimizar los recursos disponibles. Desde esta perspectiva, el diseño de dispositivos médicos debe orientarse no solo a su funcionalidad, sino también a su integración segura y duradera en el entorno biológico.

| 63

64 | Apéndice H. Anexo de sostenibilización curricular

En este proyecto, se ha propuesto un stent inteligente que incorpora un sensor capacitivo y un sistema de comunicación inalámbrica mediante acoplamiento inductivo, eliminando así la necesidad de baterías. Esta decisión tecnológica representa un avance significativo en términos de sostenibilidad, ya que evita el uso de materiales contaminantes y prolonga la vida útil del dispositivo sin necesidad de intervenciones quirúrgicas adicionales.

Asimismo, se ha realizado una cuidadosa selección de materiales biocompatibles y estables, como el Nitinol, el PDMS y la poliimida, con el objetivo de garantizar la seguridad del paciente y minimizar el deterioro del dispositivo a lo largo del tiempo. Esta elección contribuye tanto a la sostenibilidad clínica como a la reducción de residuos biomédicos.

## H.3. Competencias de sostenibilidad desarrolladas

A lo largo del desarrollo del TFG, se han aplicado y reforzado diversas competencias vinculadas a la sostenibilidad en el ámbito de la Ingeniería de la Salud:

Diseño de soluciones tecnológicas responsables: La propuesta del dispositivo se basa en un funcionamiento pasivo, sin necesidad de fuentes energéticas externas, lo que reduce el consumo de recursos y mejora la eficiencia clínica.

Enfoque preventivo en la atención sanitaria: El sensor capacitivo permite detectar alteraciones en la presión o rigidez arterial, facilitando la prevención de eventos cardiovasculares graves, lo cual promueve un modelo sanitario más proactivo y sostenible.

Análisis ético y manejo responsable de datos: En el diseño del sistema de monitorización se ha considerado la necesidad de proteger la privacidad del paciente.

Aplicación de pensamiento multidisciplinar: El proyecto integra conocimientos de bioingeniería, ciencia de materiales, electrónica, biología y medicina, demostrando la importancia de la colaboración entre disciplinas para abordar problemas de salud complejos desde una perspectiva sostenible.

H.4. Aplicación práctica en el TFG | 65
H.4. | Aplicación práctica en el TFG

La validación del stent inteligente se ha basado en la creación de modelos matemáticos para estudiar algunos aspectos como la expansión térmica del dispositivo, el comportamiento del sensor y la frecuencia de resonancia del sistema de comunicación. Además, se ha desarrollado una aplicación interactiva que permite visualizar el stent en 3D y simular su funcionamiento, fomentando el uso de herramientas digitales para mejorar la comprensión de la tecnología propuesta.

Todo este desarrollo se ha orientado a una mejora en la eficiencia diagnóstica y a una reducción en el uso de recursos clínicos, apoyando la sostenibilidad del sistema sanitario desde una doble perspectiva: tecnológica y organizativa. El dispositivo, además de cumplir una función terapéutica, se concibe como una herramienta de monitorización continua que puede integrarse en estrategias de medicina preventiva y personalizada.

### H.4.1. Conclusión

El Trabajo Fin de Grado demuestra que es posible integrar principios de sostenibilidad en todas las fases del desarrollo de una tecnología sanitaria, desde el diseño conceptual hasta su aplicación práctica. La sostenibilidad se centra en satisfacer las necesidades actuales sin comprometer las de las futuras generaciones, está se refleja en la elección de materiales, en la eficiencia energética del sistema, en la reducción de intervenciones médicas y en la consideración ética de los datos generados.

En el contexto de la Ingeniería de la Salud, la innovación tecnológica debe tener en cuenta su impacto social, ambiental y económico. Por tanto, este proyecto pone de manifiesto que la sostenibilidad no es un complemento, sino una condición fundamental para garantizar un sistema de salud más justo, resiliente y preparado para los desafíos futuros. La colaboración entre disciplinas, la responsabilidad en el diseño y la anticipación de necesidades son pilares clave para construir soluciones sanitarias sostenibles que mejoren la calidad de vida y cuiden del entorno al mismo tiempo.

# Bibliografía

[1] Lenovo, “Lenovo V15 G2 ITL – Ordenador portátil,” 2024.
[2] A. Inc., “Autodesk inventor,” 2025. Accedido: 2025-06-09.
[3] I. España, “¿cuánto gana un ingeniero biomédico en españa?,” 2025. Accedido: 2025-06-09.
[4] S. S. y. M. Ministerio de Inclusión, “Cotización / recaudación de trabajadores,” 2025. Accedido: 2025-06-09.
[5] “Reglamento (ue) 2017/745 del parlamento europeo y del consejo de 5 de abril de 2017 sobre los productos sanitarios, por el que se deroga la directiva 90/385/cee del consejo y la directiva 93/42/cee del consejo.” https://eur-lex.europa.eu/legal-content/ES/TXT/PDF/?uri=CELEX:32017R0745, (https://eur-lex.europa.eu/legal-content/ES/TXT/PDF/?uri=CELEX:32017R0745) Apr. 2017. Diario Oficial de la Unión Europea, L 117, 5.5.2017, p. 1–175.
[6] “Organización internacional de normalización (iso) - sitio oficial.” https: //www.iso.org/es, 2025.
[7] “Agencia española de medicamentos y productos sanitarios (aemps) – sitio oficial.” https://www.aemps.gob.es/, 2025.
[8] “Ley 24/2015, de 24 de julio, de patentes.” https://www.boe.es/buscar/act.php?id=BOE-A-2015-8328, (https://www.boe.es/buscar/act.php?id=BOE-A-2015-8328) July 2015. BOE núm.177, de 25 de julio de 2015, pp.58355–58399. Consolidado vigente; acceso el 9 de junio de 2025.
[9] “Reglamento (ue) 2016/679 del parlamento europeo y del consejo, de 27 de abril de 2016, relativo a la protección de las personas físicas

67

68 | Bibliografía
| en lo que respecta al tratamiento de datos personales y a la libre circulación de estos datos (reglamento general de protección de datos).” https://www.boe.es/doue/2016/119/L00001-00088.pdf, May 2016. DO L119 de 4 de mayo de 2016, pp.1–88; acceso el 9 de junio de 2025.
[10] “Ley orgánica 3/2018, de 5 de diciembre, de protección de datos per-
| sonales y garantía de los derechos digitales.” https://www.boe.es/ buscar/act.php?id=BOE-A-2018-16673, (https://www.boe.es/buscar/act.php?id=BOE-A-2018-16673) Dec. 2018. BOE núm.294, de 6 de diciembre de 2018, pp.119788–119857; entrada en vigor el 7 de

diciembre de 2018; acceso el 9 de junio de 2025.

[11] “Directiva 2014/53/ue del parlamento europeo y del consejo, de 16 de
| abril de 2014, relativa al armonización de las legislaciones de los estados miembros en materia de equipos radioeléctricos y por la que se deroga la directiva 1999/5/ce.” https://www.boe.es/doue/2014/153/L00062- 00106.pdf, (https://www.boe.es/doue/2014/153/L00062-00106.pdf) May 2014. DOL153 de 22 de mayo de 2014, pp.62–106;

acceso el 9 de junio de 2025.

[12] G. Bastarrika Alemañ, A. Alonso Burgos, P. M. Azcárate Agüero,
S. Castaño Rodríguez, J. C. Pueyo Villoslada, and E. Alegría Ezque-
| rra, “Anatomía normal, variantes anatómicas y anomalías del origen y trayecto de las arterias coronarias por tomografía computarizada

multicorte,” Radiología, vol. 50, no. 3, pp. 197–206, 2008.

[13] D. Stoeckel, A. Pelton, and T. Duerig, “Stents autoexpandibles de niti-
| nol: consideraciones sobre el material y el diseño,” European Radiology,
vol. 14, pp. 292–301, 2004.
[14] B. J.L, “Material dieléctrico: Qué es, tipos, propiedades y ejemplos.”
| https://electronicaonline.net/electronica/dielectrico/,
2022.
[15] K. Tanaka, “A thermomechanical sketch of shape memory effect: One-
| dimensional tensile behavior,” Res Mechanica, vol. 18, no. 3, pp. 251–263,
1986.
[16] J. A. Shaw and S. Kyriakides, “Thermomechanical aspects of niti,”
| Journal of the Mechanics and Physics of Solids, vol. 43, no. 8, pp. 1243–
1281, 1995.
[17] J. L. M. Poiseuille, “Recherches expérimentales sur le mouvement des
| liquides dans les tubes de très petits diamètres,” Mémoires de l’Académie des Sciences de l’Institut de France, vol. 9, pp. 433–544, 1840.

Bibliografía | 69
[18] L. Antiga, M. Piccinelli, L. Botti, B. Ene-Iordache, A. Remuzzi, and
D. A. Steinman, “Un marco de modelado basado en imágenes para la hemodinámica computacional específica del paciente,” Medical Biological Engineering Computing, vol. 46, no. 11, pp. 1097–1112, 2008.
[19] F. M. White, Fluid Mechanics. New York: McGraw-Hill Education, 7th ed., 2011.
[20] M. Götberg, E. H. Christiansen, I. J. Gudmundsdottir, L. Sandhall,
M. Danielewicz, L. Jakobsen, S.-E. Olsson, P. Öhagen, H. Olsson,
E. Omerovic, F. Calais, P. Lindroos, M. Maeng, T. Tödt, D. Venetsanos,
S. K. James, A. Kåregren, M. Nilsson, J. Carlsson, D. Hauer, J. Jensen, A.-C. Karlsson, G. Panayi, D. Erlinge, and O. Fröbert, “Instantaneous wave-free ratio versus fractional flow reserve to guide pci,” New England Journal of Medicine, vol. 376, no. 19, pp. 1813–1823, 2017.
[21] H. Wheeler, “Simple inductance formulas for radio coils,” Proceedings of the Institute of Radio Engineers, vol. 16, no. 10, pp. 1398–1400, 1928.
[22] Modern Physics, “Sensor capacitivo | precisión, sensibilidad y aplicacio-
nes,” 2025. Accedido el 26 de mayo de 2025.
[23] V. Bande, S. Pop, D. Pitica, and C. Ioan, “Electrical model of a capacitive based level sensor,” Proceedings of the International Spring Seminar on Electronics Technology, pp. 333–338, 05 2013.
[24] Votatera, “Resonancia en circuitos rlc: Eficiencia, sintonización y teoría,” 2024. Accedido el 28 de mayo de 2025.
[25] OpenStax, Física universitaria volumen 2. OpenStax, 2021. Accedido el 28 de mayo de 2025.
[26] M. Kesler, “Highly resonant wireless power transfer: Safe, efficient, and over distance,” tech. rep., WiTricity Corporation, 2013. Accessed via Wayback Machine.
[27] University of Washington, “Thin walled pressure vessels,” n.d. Accessed: 2025-06-07.
[28] University of Arizona, “Opti 222 mechanical design in optical engineering,” n.d. Accessed: 2025-06-07.
[29] University of Washington, “Thick walled cylinders,” n.d. Accessed: 2025-06-07.

70 | Bibliografía
[30] “Cálculo de factor de seguridad probabilístico basado en la validación metrológica de modelos ingenieriles,” e-medida, no. 12, 2017. Accedido el 7 de junio de 2025.
[31] C. M. Vemury, M. Corradi, F. Abozaid, and A. Charles, “The behaviour of nitinol wire bundles for structural applications,” Recent Progress in Materials, vol. 3, no. 1, p. 009, 2021.
[32] C. Ciancaglini, “Hidrodinamia de la circulación vascular periférica normal y patológica,” Revista Costarricense de Cardiología, vol. 6, no. 2, pp. 43–61, 2004.
[33] P. R. Moreno and J. H. del Portillo, “Isquemia miocárdica: conceptos básicos, diagnóstico e implicaciones clínicas. primera parte,” Revista Colombiana de Cardiología, vol. 23, no. 5, pp. 403–409, 2016.
[34] OpenStax, “20.02: Flujo sanguíneo, presión arterial y resisten-
cia.” | https://espanol.libretexts.org/Salud/Anatomia_y_
Fisiologia/Libro%3A_Anatom%C3%ADa_y_Fisiolog%C3%ADa_ 1e_%28OpenStax%29/Unit_4%3A_Fluidos_y_Transporte/20% 3A_El_sistema_cardiovascular_-_Vasos_Sangu%C3%ADneos_y_ Circulaci%C3%B3n/20.02%3A_Flujo_Sangu%C3%ADneo%2C_Presi% C3%B3n_Arterial_y_Resistencia, (https://espanol.libretexts.org/Salud/Anatomia_y_Fisiologia/Libro%3A_Anatom%C3%ADa_y_Fisiolog%C3%ADa_1e_%28OpenStax%29/Unit_4%3A_Fluidos_y_Transporte/20%3A_El_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) note = Consultado el 7 de junio de 2025, s.f.
[35] “Constantes electromagnéticas.” Consultado el 7 de junio de 2025.
[36] T. de los Plásticos, “Poliimida,” 2011. Consultado el 7 de junio de 2025.
[37] U. M. N. Granada, “Unidad 3: Ley de coulomb y ley de gauss,” 2025. Accedido: 7 de junio de 2025.
[38] S. K. Patel, B. Behera, B. Swain, R. Roshan, D. Sahoo, and A. Behera, “A review on niti alloys for biomedical applications and their biocompatibility,” Materials Today: Proceedings, vol. 33, pp. 5548–5551, 2020. 2nd International Conference on Processing and Characterization of Materials.
[39] F. Rigo, V. Spadotto, R. S. Fattore, P. Renda, C. Cugini, and M. Agnoletto, “Normal physiologic coronary flow velocity gradient across the left anterior descending artery in healthy asymptomatic subjects,” Exploration of Cardiology, vol. 1, pp. 42–48, 2023.

Bibliografía | 71
[40] B. Lee, Y. Jia, S. A. Mirbozorgi, M. Connolly, X. Tong, Z. Zeng,
B. Mahmoudi, and M. Ghovanloo, “An inductively-powered wireless neural recording and stimulation system for freely-behaving animals,” IEEE Transactions on Biomedical Circuits and Systems, vol. 13, no. 2, pp. 413–424, 2019.
[41] M. H. Ghaed, Wireless Transceivers for Implantable Microsystems. PhD thesis, University of Michigan, 2013. Accedido: 2025-06-09.

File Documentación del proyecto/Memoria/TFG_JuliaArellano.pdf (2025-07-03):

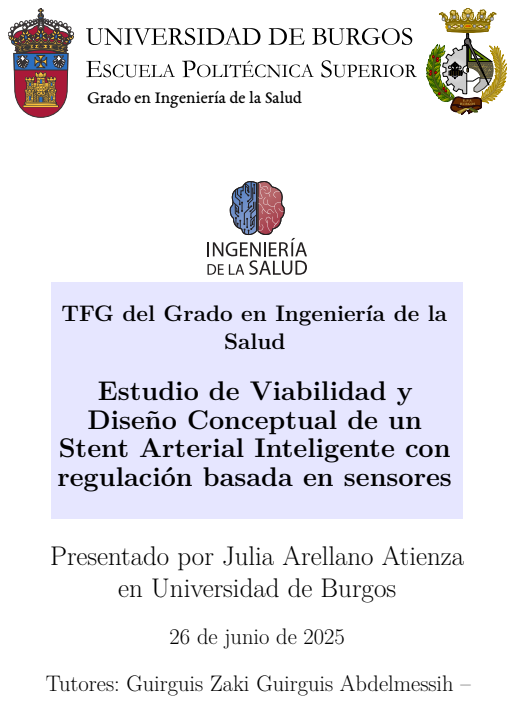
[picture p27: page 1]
Salud

Grado en Ingeniería de la Salud

TFG del Grado en Ingeniería de la

Estudio de Viabilidad y
Diseño Conceptual de un
Stent Arterial Inteligente con
regulación basada en sensores

Presentado por Julia Arellano Atienza
en Universidad de Burgos

26 de junio de 2025

Tutores: Guirguis Zaki Guirguis Abdelmessih –

Grado en Ingeniería de la Salud

D. Guirguis Zaki Guirguis Abdelmessih, profesor del departamento de Ingeniería Electromecánica, área de Tecnología Electrónica.

Expone:

Que el alumno D. Julia Arellano Atienza, con DNI 78774976E, ha realizado el Trabajo final de Grado en Ingeniería de la Salud titulado Estudio de Viabilidad y Diseño Conceptual de un Stent Arterial Inteligente con regulación basada en sensores.

Y que dicho trabajo ha sido realizado por el alumno bajo la dirección del que suscribe, en virtud de lo cual se autoriza su presentación y defensa.

### En Burgos, 26 de junio de 2025

Vº. Bº. del Tutor:

D. Guirguis Zaki Guirguis Abdelmessih

i

Resumen

En las últimas décadas, la incidencia de enfermedades cardiovasculares ha aumentado de forma significativa, conviertiéndose en una de las principales causas de mortalidad a nivel mundial. Ante esta problemática, el proyecto aborda el desarrollo conceptual de un stent inteligente para arterias coronarias, con el objetivo de mejorar el seguimiento clínico de los pacientes. Este dispositivo incorpora componentes electrónicos que permiten una monitorización continua y en tiempo real del estado de la arteria, facilitando la detección precoz de complicaciones. El diseño se ha basado en la revisión de estudios científicos actuales, y su viabilidad ha sido evaluada mediante aproximaciones matemáticas que analizan su comportamiento estructural y funcional. Asimismo, se ha desarrollado una aplicación interactiva que permite tanto visualizar los resultados obtenidos como la interacción por parte del usuario, contribuyendo a una mejor comprensión del sistema propuesto.

Descriptores

Stent inteligente, arterias coronarias, sensores electrónicos, monitorización continua, detección temprana, dispositivos médicos, comunicación inalámbrica, modelos matemáticos.

ii

Abstract

In recent decades, the incidence of cardiovascular disease has increased significantly, becoming one of the leading causes of mortality worldwide. Given this issue, the project addresses the conceptual development of a smart stent for coronary arteries, with the goal of improving the clinical follow-up of patients. This device incorporates electronic components that allow for continuous, real-time monitoring of the artery’s condition, facilitating early detection of complications. The design was based on a review of current scientific studies, and its feasibility was evaluated using mathematical approximations that analyze its structural and functional behavior. An interactive application has also been developed that allows users to view the results obtained and interact with the system, contributing to a better understanding of the proposed system.

Keywords

Smart stent, coronary arteries, electronic sensors, continuous monitoring, early detection, medical devices, wireless communication, mathematical models.

# Índice general

Índice general | iii
Índice de figuras | v
Índice de tablas | vi
Introducción | 1
Objetivos | 3
Conceptos teóricos | 5
Metodología | 15
Resultados | 23
Conclusiones | 31

iii

iv | ÍNDICE GENERAL
Lineas de trabajo futuras | 33
Bibliografía | 35

# Índice de figuras

3.1. Imagen de una endoprótesis | 5
3.2. Comparación entre angioplastia con balón (a) y sin balón con
stent autoexpandible (b) | | 6
3.3. Ilustración de un stent inteligente | | 10
5.1. Diseño final del stent inteligente. Fuente propia | | 23
5.2. Diseño completo del sensor capacitivo. Fuente propia | | 24
5.3. Página inicial de la app. Fuente propia | | 26

v

# Índice de tablas

4.1. Resumen de los parámetros técnicos del stent inteligente . . . . 17

vi
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

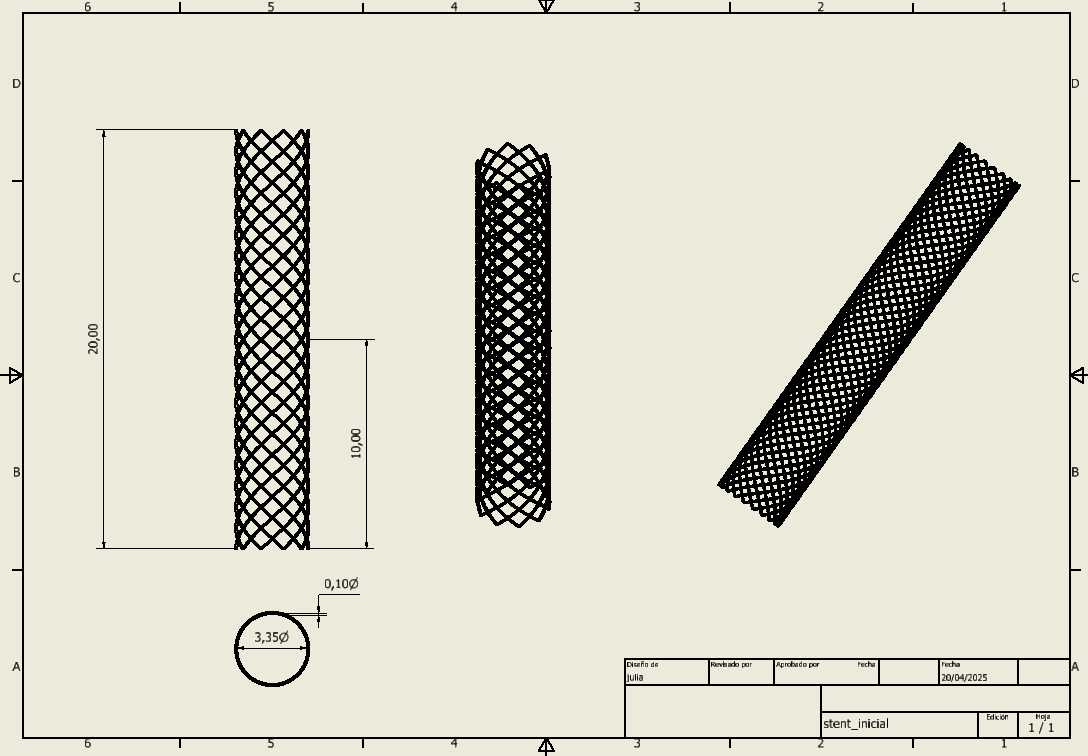
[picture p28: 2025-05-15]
Diseño/Planos/stent_inicial.png

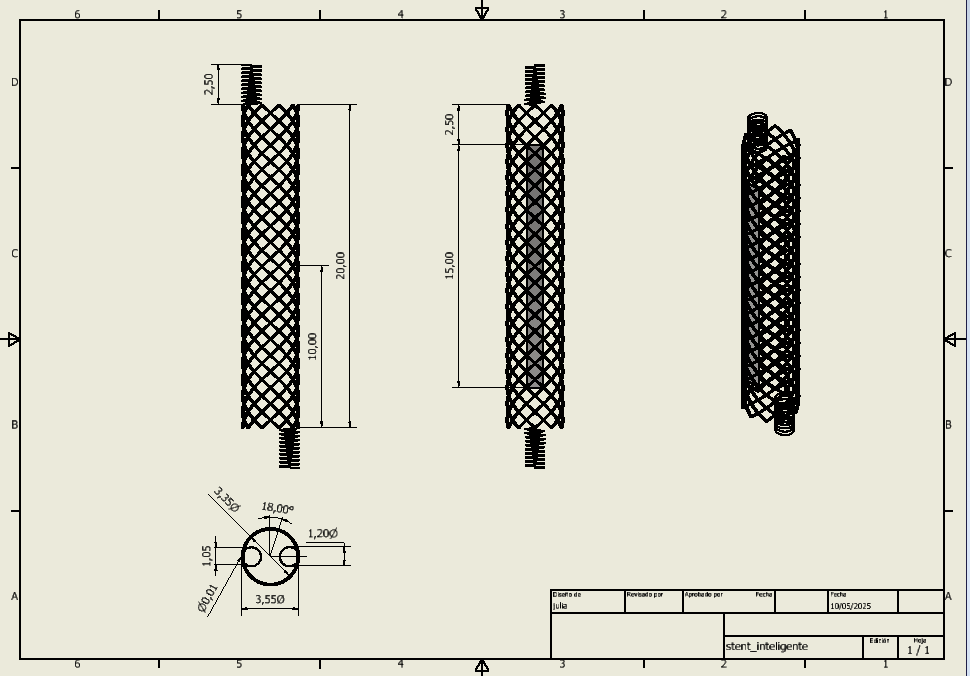
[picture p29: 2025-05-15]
Diseño/Planos/plano_stent_inteligente.png

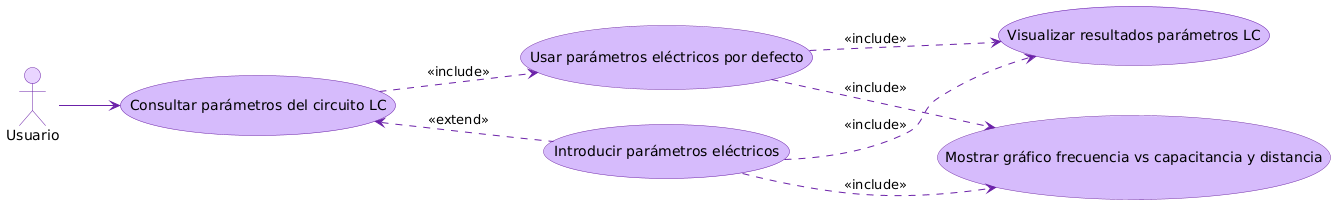
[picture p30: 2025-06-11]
Documentación del proyecto/Diagramas/caso_uso_circuitoLC.png

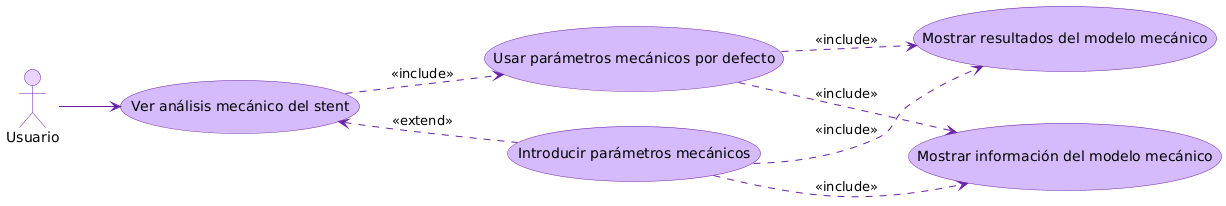
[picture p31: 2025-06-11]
Documentación del proyecto/Diagramas/caso_uso_ev_tensiones.png

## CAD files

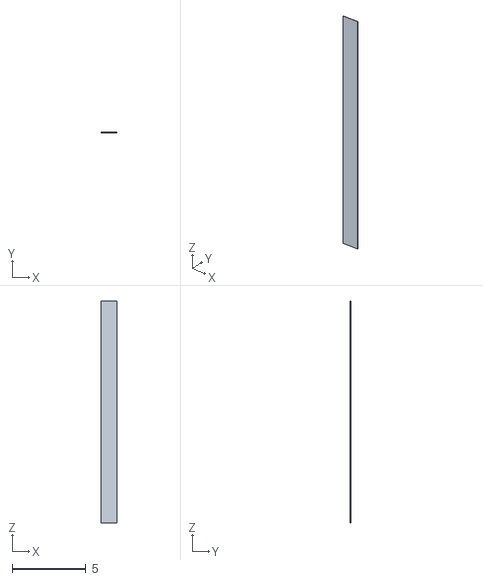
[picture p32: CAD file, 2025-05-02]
app/Sensor_completo.stl
1.05 x 0.0152 x 15.0

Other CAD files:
Diseño/Planos/Sensor_completo_1.idw
Diseño/Planos/stent_inicial.idw
Diseño/Planos/stent_inteligente.idw
Diseño/Prototipos/Sensor_completo.ipt
stent_inteligente.ipt

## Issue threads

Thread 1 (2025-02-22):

Búsqueda de artículos

JuliaArellano, 2025-02-22:

JuliaArellano, 2025-03-06:
las referencias se encuentran subidas en la carpeta

JuliaArellano, 2025-04-08:
se han añadido nuebas referencias utilizadas en la realización dde la memoria

JuliaArellano, 2025-04-17:
se suben nuevas para el desarrollo de la memoria

Closed 2025-06-29.

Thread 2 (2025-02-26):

Búsqueda de herrramientas de simulación

JuliaArellano, 2025-02-26:

JuliaArellano, 2025-03-15:
- Diámetro 3 mm
 - Tamaño del hilo : 0.1 mm
 - Paso : 5mm

JuliaArellano, 2025-03-15:
Se ha alargado pero los parámetros estaban definidos 01-07 marzo, se visualizará en el cronograma

Closed 2025-03-15.

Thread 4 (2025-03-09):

creacion del stent clásico

JuliaArellano, 2025-03-09:

JuliaArellano, 2025-03-09:
En versiona actual del stent clásico se encuentra en : main/Stent.ipt

JuliaArellano, 2025-03-13:
el stent clasico ya ha sido creado la versión se encuentra en el main, esta versión posiblemente desaparecerá

Closed 2025-03-13.

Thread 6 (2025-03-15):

Adaptación de los parámetros

JuliaArellano, 2025-03-15:

JuliaArellano, 2025-03-15:
Tras la búsqueda de los sensores , los parámetros han sido actualizados en la carpeta creación_diseño que contiene un txt con parametros de las modificación que va a ir haciendose en el modelo

JuliaArellano, 2025-03-19:
Hasta hoy se han añadido las dimensiones de stent , sensores y algo de información sobre el método de comunicación

JuliaArellano, 2025-03-19:
Se ha añadido más información sobre como se comunicara el stent con el exterior

Closed 2025-03-27.

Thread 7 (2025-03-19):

Integración del sensor al diseño inicial

JuliaArellano, 2025-03-19:

JuliaArellano, 2025-03-21:
Una vez, que he obtenido los parámetros del sensor he creado los electrodos del sensor y se han subido

JuliaArellano, 2025-03-24:
se ha colocado el sensor en su sitio

JuliaArellano, 2025-03-24:
se ha creado una estructura que engloba al sensor , posteriormente se hará el diseño del sensor con sus capas

Closed 2025-03-24.

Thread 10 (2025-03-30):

Diseño de las capas/ estructura del sensor

JuliaArellano, 2025-03-30:

JuliaArellano, 2025-04-05:
base del sensor unidaa los electroso subida

JuliaArellano, 2025-04-05:
se lleva haciendo toda la semana falta la capa de PDMS que recubre el sensor

JuliaArellano, 2025-04-06:
se ha subido el sensor completo

Closed 2025-04-06.

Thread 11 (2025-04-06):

Estudio del expasión del stent

JuliaArellano, 2025-04-06:

JuliaArellano, 2025-04-08:
la idea principal era usar un simulador para ralizar el estudio de la viabilidad , ante las distintas recciones que presenta principalmente , el ordenador es incapaz de soportar estos programas se ha decidido realizar mediante un aproximación matemática y para las representaciones python

JuliaArellano, 2025-04-12:
Primer ensayo del modelo: expansión del stent

JuliaArellano, 2025-04-12:
Para ello, hay que tener en cuenta que es un modelo con memoria a forma varia en función de su temperatura, existen 2 fases las cuales están en el notebook

JuliaArellano, 2025-04-19:
se han probado varias opciones pero aun no funciona funciona bien

JuliaArellano, 2025-04-25:
hecho

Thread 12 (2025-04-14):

Búsqueda de parámetros  utilizados en la viabilidad del diseño

JuliaArellano, 2025-04-14:

JuliaArellano, 2025-04-21:
Parámetros del nitinol encontrados en https://www.lidsen.com/journals/rpm/rpm-03-01-009

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

JuliaArellano, 2025-04-30:
parámetros del flujo sanguíneo:

- En reposo : 3.34e-6 (m³/s)
-  En actividad :16.67 e-6 (m³/s)

Web: https://www.elsevier.es/es-revista-revista-colombiana-cardiologia-203-resumen-isquemia-miocardica-conceptos-basicos-diagnostico-S0120563316301000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,reserva%20de%20flujo%20sangu%C3%ADneo%20coronario.

JuliaArellano, 2025-05-01:
-  viscosidad de la sangre : 3.5e-3 (Pa·s)

JuliaArellano, 2025-05-13:
Parámetros para circuito LC:
- resistividad del oro : 2.44e-8 ohmios x metro
- Permitividad relativa de la poliamida: 3.2

JuliaArellano, 2025-05-13:
todos los ensayos hechos

Closed 2025-05-13.

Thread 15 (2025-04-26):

Cálculo de perfil de velocidad de Poiseuille en el stent

JuliaArellano, 2025-04-26:

JuliaArellano, 2025-04-30:
se ha ido realizando durante estos dias, hoy se terminara y se adjuntara

JuliaArellano, 2025-05-01:
al final ayer no se puedo terminar se terminará hoy

JuliaArellano, 2025-05-01:
se encuentra en la carpeta de viabilidad en el [Modelo_computacional.ipynb](https://github.com/JuliaArellano/Trabajo_Fin_Grado_GIS/blob/main/Viabilidad/Modelo_computacional.ipynb)

JuliaArellano, 2025-05-01:
hecho

Closed 2025-05-01.

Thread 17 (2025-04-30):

Creación de la app y configuración de la pantalla de inicio

JuliaArellano, 2025-04-30:

JuliaArellano, 2025-04-30:
App se va a realizar en streamlit

JuliaArellano, 2025-04-30:
se ha creado el documento y se esta realizando la estructura de la app

JuliaArellano, 2025-04-30:
se va a conectar con la nube de streamlit desde github

JuliaArellano, 2025-04-30:
link de la app stremalit_cloud : https://tfg-gis-stent-inteligente.streamlit.app/

JuliaArellano, 2025-04-30:
webs de donde se ha cogido los emoticonos : https://emojipedia.org/es/search

JuliaArellano, 2025-04-30:
primera version de la pantalla inicio hecha

JuliaArellano, 2025-05-01:
inicio hecho hasta los modelos de viabilidad hecho , ahora realizare #18

JuliaArellano, 2025-05-13:
se ha añadido información y se ha terminado

Closed 2025-05-13.

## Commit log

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2025-02-22 Creacion de carpeta de imagenes con imagen UBU
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2025-02-25 Generacion de una nueva version de stent básico
    [Stent_1.0001.ipt, Stent_1.ipt, Stent_v1.ipt]
2025-02-25 Eliminación de la version anterior del stent
    [Stent_v1.ipt]
2025-02-26 Creación del cronograma de trabajo
    [Cronograma_TFG.xlsx]
2025-03-07 Creacion de la placa de amarre, sensor y pruebade ensamblaje de los componentes
    [Ensamblaje1.iam, placa de amarre.ipt, sensor.ipt]
2025-03-07 añadida la web doonde se ha sacado la info sobre el sensor que se va a crear
2025-03-09 se ha añadido una version del stent en formato .stl para poder visualizarlo en python
2025-03-09 se ha añadido codigo para visualizar el archivo de stl con python
2025-03-09 Se ha creado la carpeta de visualización con los archivos de .stl y el .ipynb
2025-03-09 Modificación del cronograma
    [Cronograma_TFG.xlsx]
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2025-03-13 Se ha añadido una carteta con un documento que contiene las dimensiones del diseño
2025-03-15 Se ha añadido info en la carpeta caracteristicas_diseño sobre la estructura de los sensores
2025-03-15 Actualización del cronograma
    [Cronograma_TFG.xlsx]
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2025-03-21 Eliminación de archivos
    [Ensamblaje1.iam, placa de amarre.ipt, sensor.ipt]
2025-03-21 Creación del sensor
    [electrodos.ipt]
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2025-03-24 Actualización de stent con el sensor , senosr colocado en la posición correcta
2025-03-24 Actualización del cronograma de tareas
    [Cronograma_TFG.xlsx]
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2025-03-30 Stent con reguladores hecho
    [stent_3.ipt]
2025-04-05 Sensor con electrodos sin PDMS
    [sensor_electrodo.ipt]
2025-04-06 Sensor completado
    [Estrucutra_sensor_completo.ipt, sensor_electrodo.ipt]
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2025-04-11 Script donde se haran los ensayos de viabilidad
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2025-04-19 Se ha subido el modelo : primero se han definido las temeraturas de las fases del nitinol
2025-04-19 Se ha subido el modelo : función de cambio de fase añadida
2025-04-19 Se ha incluido las anexos, se ha avanzado con el anexo D
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2025-04-20 Se ha añadido la carpeta planos junot al plano del stent_incial
    [stent_inicial.idw]
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2025-04-22 Actualización y corrección del sensor
    [Estrucutra_sensor_completo.ipt, Sensor_completo.ipt, electrodos.ipt]
2025-04-26 Actualización cronograma
    [Cronograma_TFG.xlsx]
2025-04-26 Plano del sensor
    [Sensor_completo_1.idw]
2025-04-30 Plano del stent inteligente final
    [stent_inteligente.idw]
2025-04-30 Creación de la app
    [stent_inteligente.ipt]
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2025-04-30 Create requirements.txt
    creación de la documento de paquetes requeridos para el funcionamiento de la app
2025-04-30 Actualización de la app , creación de la barra lateral
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2025-05-01 Se ha añadido una evaluación de la estenosis en el perfil de seguridad
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2025-05-01 Actualización cronograma y modelos viabilidad
    [Cronograma_TFG.xlsx]
2025-05-02 Se ha añadido info en la pestaña de vista app.py
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2025-05-02 Archivos a visualizar en la app
    [Sensor_completo.stl]
2025-05-06 Creando y añadidendo información a la pestaña de velocidad del flujo app.py
2025-05-08 Actualización en el analisis eléctrico del circuito LC
2025-05-08 Actualización se ha añadidocálculo de la inducancia de las bobinas del stent
2025-05-08 Actualización se ha añadido cálculo de la capacitancia del sensor
2025-05-08 Actualización se ha añadido cálculo de la frecuencia de resonancia
2025-05-08 Actualización se ha añadido factor de calidad Q del circuito LC
2025-05-08 Actualización se ha añadido distancia máxima posible para la comunicación
2025-05-10 Actualización en los paremetros electricos del circuito LC
2025-05-10 Actualización en la bobina del stent, con cambios en planos y stent
    [stent_inteligente.idw]
2025-05-12 Actualizaciónn de la pestaña denominada análisis del sistema
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2025-05-13 Actualización evaluación mécanica en a la app.py y en el script
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2025-05-13 Actualización de diametro de bobinas en el stent por fallo
    [stent_inteligente.0007.idw, stent_inteligente.idw]
2025-05-14 Actualización de los anexos de la memoria y adicción de algun articulo nuevo utilizado
2025-05-15 Actualización de los planos y creación de fotos de los planos en .png
    [Sensor_completo_1.0006.idw, Sensor_completo_1.idw, stent_inteligente.0007.idw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]
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2025-05-20 se ha avanzado con los anexos en concreto con el E y se ha creado una carpeta para incluir algunos diagramas mostrados en la memoria
2025-05-23 Nuevos diagramas realizados y incluidos en el anexo E diseño
2025-05-25 Correción de un error aproximación Nitinol
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2025-06-09 Correción de errores
2025-06-09 Actualización del cronograna, anexos y correción de errores en viabilidad
    [Cronograma_TFG.xlsx]
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2025-06-10 Cambio de las estructura de ficheros a una estructura modular
    [Cronograma_TFG.xlsx, Sensor_completo.ipt, Sensor_completo_1.0006.idw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]
2025-06-10 Actualización de los anexos, anexo C hecho y cambio de nombres en archivos
    [Sensor_completo_1.0006.idw, stent_inteligente.0008.idw]
2025-06-11 Se han añadido los diagramas de casos de unos de la app del apendice F
2025-06-11 Correción de errores en los anexos
2025-06-12 Actualización de la memoria, realización de técnicas utilizadas
2025-06-13 Actualización de la memoria, hecho resumen, abstract e introducción
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2025-06-14 Eliminado el error
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2025-06-16 Actualización de memoria de las lineas futuras y las conclusiones
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2025-06-19 Cambios en el cronograma
    [Cronograma_TFG.xlsx]
2025-06-19 Correción de errores memoria y anexos
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
